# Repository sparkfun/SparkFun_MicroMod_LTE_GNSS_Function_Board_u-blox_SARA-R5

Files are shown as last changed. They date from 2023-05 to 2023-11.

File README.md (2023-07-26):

SparkFun MicroMod LTE GNSS Function Board - u-blox SARA-R5
========================================

SparkFun MicroMod LTE GNSS Function Board - u-blox SARA-R5 (https://www.sparkfun.com/products/18431)

[*SparkFun MicroMod LTE GNSS Function Board - u-blox SARA-R5 (DEV-18431)*](https://www.sparkfun.com/products/18431)

Using the u-blox SARA-R510M8S, this function board adds LTE and GNSS capabilities to the MicroMod EcoSystem.

Documentation
--------------
* **[Library](https://github.com/sparkfun/SparkFun_u-blox_SARA-R5_Arduino_Library)** - Arduino library for the SparkFun MicroMod LTE GNSS Function Board u-blox SARA-R5.
* **[Hookup Guide](https://docs.sparkfun.com/SparkFun_MicroMod_LTE_GNSS_Function_Board_u-blox_SARA-R5)** - Basic hookup guide for the SparkFun MicroMod LTE GNSS Function Board u-blox SARA-R5.

Product Versions
----------------
* [DEV-18431](https://www.sparkfun.com/products/18431) - Initial release, v1.1

License Information
-------------------

This product is _**open source**_!

Please review the LICENSE.md file for license information.

If you have any questions or concerns on licensing, please contact technical support on our [SparkFun forums](https://forum.sparkfun.com/viewforum.php?f=152).

Distributed as-is; no warranty is given.

- Your friends at SparkFun.

_<COLLABORATION CREDIT>_

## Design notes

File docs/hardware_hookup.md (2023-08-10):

If you have not already, make sure to check out the Getting Started with MicroMod: Hardware Hookup for information on inserting your Processor and Function Boards to the Main Board.

<div style="text-align: center">
  <table>
    <tr>
      <td>
        <a href="https://learn.sparkfun.com/tutorials/getting-started-with-micromod#hardware-hookup">
          <div style="text-align: center">Getting Started with MicroMod: Hardware Hookup</div>
          <hr />
          <h3 style="text-align: left">
            <b>Getting Started with MicroMod: Hardware Hookup</b>
          </h3>
        </a>
      </td>
    </tr>
  </table>
  </div>

### Inserting a SIM Card

!!!note
    ####Activate Your Hologram SIM
    If you're using a SIM card from Hologram, you'll need to follow a few quick steps to activate your SIM card.
    <ol>
      <li><a href="https://dashboard.hologram.io/">Log in</a> to your Hologram account, or <a href="https://dashboard.hologram.io/account/register">create one</a>.</li>
      <li>Click the blue <strong>+ Activate SIM</strong> button in the upper-right-corner of your Dashboard.</li>
      <br>
      <p style="text-align:center;"> <a href="https://cdn.sparkfun.com/assets/learn_tutorials/8/1/6/hologram-activate-sim.png">Activate hologram SIM</a></p>
      <br>
      <li>Select your plan – in most cases “Maker Flexible” is the way to go, but you can upgrade.</li>
      <li>Enter your SIM card’s CCID. This number can be found printed on both your nano-SIM card and in the larger digits below the bar code. Then select continue.</li>
      <li>Next you can decide whether to enable auto-refill or not and continue. Finally, you’ll be greeted with a summary page – hit “Activate” and you’re ready to go!</li>
    </ol>
    <p>For more help activating your Hologram SIM card, check out their <a  href="https://hologram.io/docs/guide/connect/connect-device/">Connect Your Device</a> documentation.</p>

Insert the SIM card into the nano SIM socket until it clicks. In this case, we used a [Hologram card](https://www.sparkfun.com/products/17117).

<div style="text-align: center;">
  <table>
    <tr align="center">
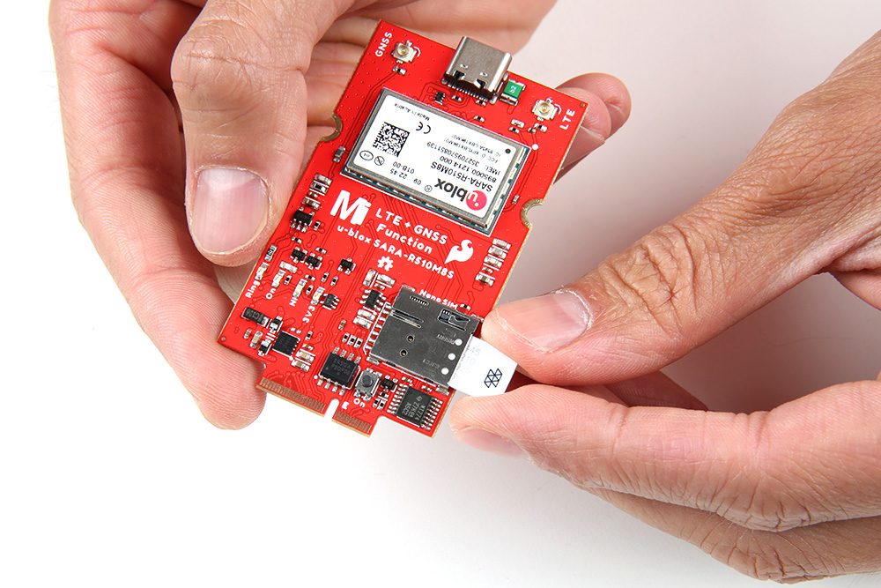
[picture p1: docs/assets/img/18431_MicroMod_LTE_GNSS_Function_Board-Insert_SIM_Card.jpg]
Insert Nano SIM Card
     <td></td>
    </tr>
  </table>
</div>

### Processor Board

Align the Processor Board's key into its M.2 connector's socket. Insert the board at an angle (~25°), push down, and tighten the screw. In this case, we had the MicroMod ESP32 Processor Board secured in the M.2 connector socket. Depending on your application, you may have a different Processor Board.

<div style="text-align: center;">
  <table>
    <tr align="center">
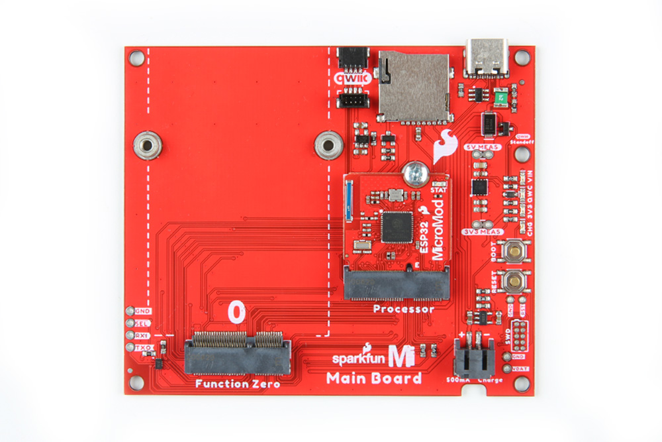
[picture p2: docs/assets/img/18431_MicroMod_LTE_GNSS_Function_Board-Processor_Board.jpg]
Insert Processor Board into Main Board
     <td></td>
    </tr>
  </table>
</div>

!!!note
    There are a variety of MicroMod Processor Boards available. However, we recommend using the ESP32, Artemis, and SAMD51 Processor Boards as these were tested to work with the SARA-R5. For the scope of this tutorial, we will be using the ESP32 Processor Board. The caveat when using the ESP32 Processor Board is that you will need to configure the pin that is connected to the voltage regulator's enable pin. This pin is used to upload code and when the ESP32 boots up. After uploading code and/or when the ESP32 has finished booting up, you will need to configure the pin as an input pullup in the `setup()`.

### Function Board

Align the Function Board's key into its M.2 connector's socket. Insert the board at an angle (~25°), push down, and tighten one of the screw to hold the board down. Attach the second screw on the other side of the board. Once the board is aligned, tighten both screws fully to secure the board.

<div style="text-align: center;">
  <table>
    <tr align="center">
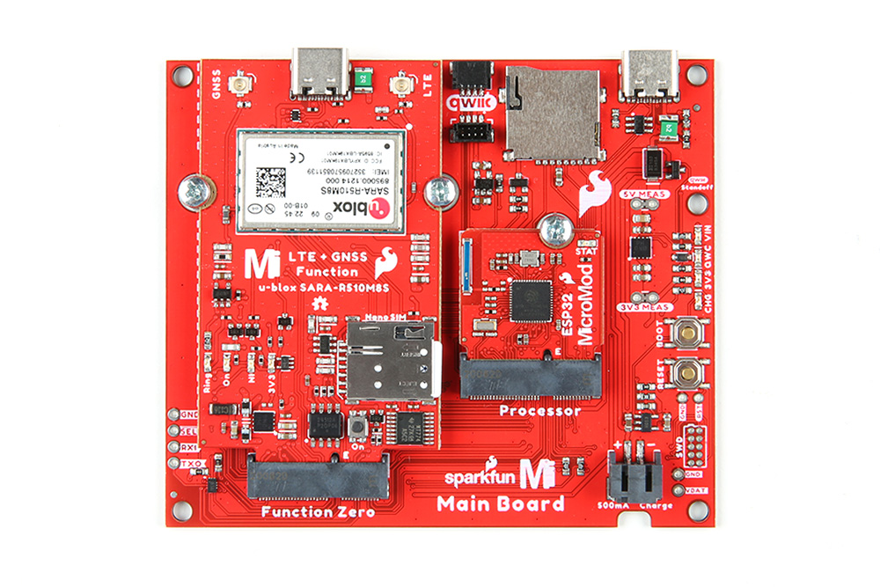
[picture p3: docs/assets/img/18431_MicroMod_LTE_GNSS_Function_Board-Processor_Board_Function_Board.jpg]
Insert Function Board into Main Board
     <td></td>
    </tr>
  </table>
</div>

### Attaching Antennas

Once the Function Boards are secure, attach any remaining cables, antennas, or components that your application may need. In this case, we would need to attach the LTE antenna, GNSS antenna, and a u.FL to SMA adapter for each antenna. For each antenna, connect the SMA connectors together and secure the connection using the hex nut until it is finger-tight. Then plug in the u.FL side of the cable into the board's u.FL connector. If you need tips on plugging in the U.FL connector, then check out our [U.FL tutorial](https://learn.sparkfun.com/tutorials/three-quick-tips-about-using-ufl).

<div style="text-align: center;">
  <table>
    <tr align="center">
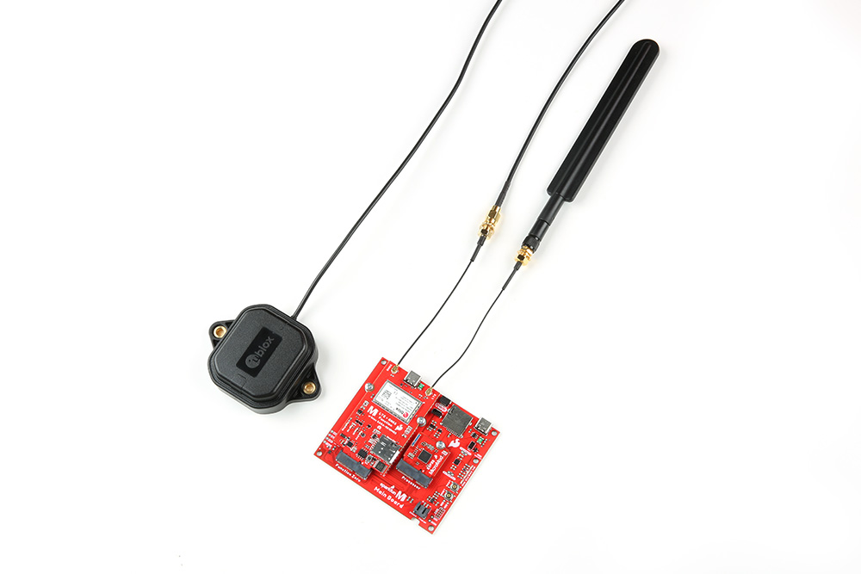
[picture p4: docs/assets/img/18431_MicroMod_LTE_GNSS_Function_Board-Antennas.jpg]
Connect u.FL to SMA cables to LTE and GNSS multi-band antenna
     <td></td>
    </tr>
  </table>
</div>

### USB Cable

Last but not least, insert a cable to the Main Board's USB port. This is useful for programming the ESP32 Processor Board, power, and serial communication.

<div style="text-align: center;">
  <table>
    <tr align="center">
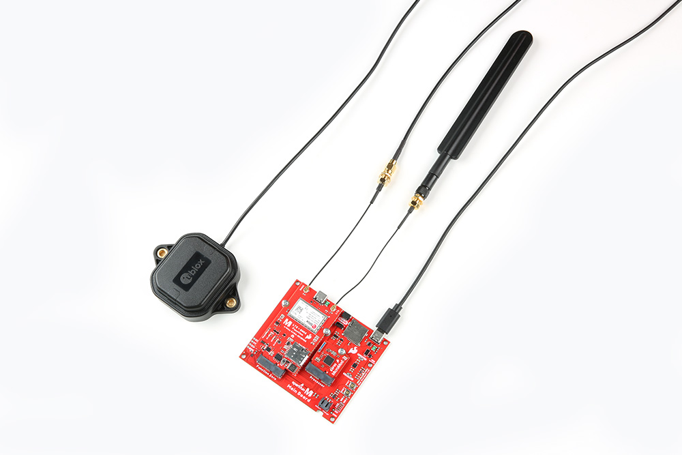
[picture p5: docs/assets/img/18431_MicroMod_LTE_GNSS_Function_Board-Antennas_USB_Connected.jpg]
USB Cable into Main Board
     <td></td>
    </tr>
  </table>
</div>

!!!note
    The USB port on the SARA-R5 Function Board is for diagnostics and is currently unavailable. While you can connect to the port for power, there currently is not much support for the diagnostics.

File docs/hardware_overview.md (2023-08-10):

We've broken out the SARA-R5 module (specifically the **SARA-R510M8S-01B**) to a MicroMod Function Board. Due to the design of the Function Board, we've rotated the board 180° relative to the label in the image shown below. In this section, we will highlight relevant components on the board. For more information about the u-blox SARA-R510M8S module, make sure to check the Resources tab.

<div style="text-align: center;">
  <table>
    <tr align="center">
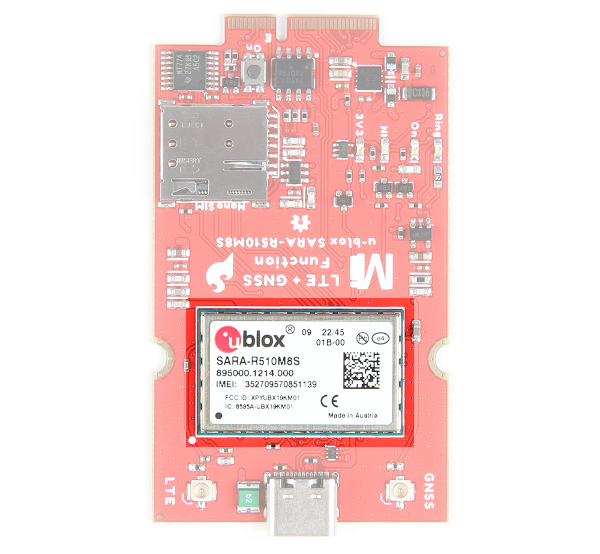
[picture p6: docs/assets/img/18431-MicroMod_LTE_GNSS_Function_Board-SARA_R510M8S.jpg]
SARA-R5 highlighted
     <td></td>
    </tr>
  </table>
</div>

### Power

The Function Board receives power typically from MicroMod Main Board's M.2 socket. Depending on your application, power can be provided via the Main Board's USB or a single cell LiPo Battery. If the Function Board's USB is also connected, a Schottky protection diode (the little rectangular black IC by the USB C connector) is included to prevent conflicting voltages. A resettable fuse is also included next to the USB connector as well. Power for the system is regulated down for the function board from the 3.3V AP7361C voltage regulator (square IC by the bottom left of the board). A dedicated 3.3V AP2112K voltage regulator (5-pin black IC) is also provided when using an active GNSS antenna. Additionally, the board includes an IC for voltage level translation (16 pin black IC on the bottom right of the board) for certain pins on the SARA-R510M8S.

<div style="text-align: center;">
  <table>
    <tr align="center">
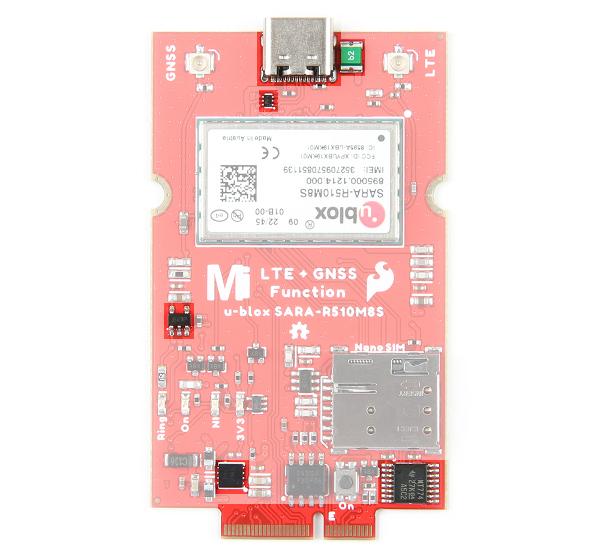
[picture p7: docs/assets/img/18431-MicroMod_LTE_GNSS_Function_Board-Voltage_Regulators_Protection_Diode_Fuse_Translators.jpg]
USB, M.2 Edge, voltage regulators, protection diodes, fuse, and logic translators highlighted
     <td></td>
    </tr>
  </table>
</div>

### USB Type C Connector

Users can connect the module to a USB port. This can power the module as well. A Schottky protection diode is included to prevent conflicting voltages when the Main Board is connected to a power source. A resettable fuse is also provided. Compared to other u-blox modules, you will this is for the diagnostic interface and not to for flashing new firmware.

<div style="text-align: center;">
  <table>
    <tr align="center">
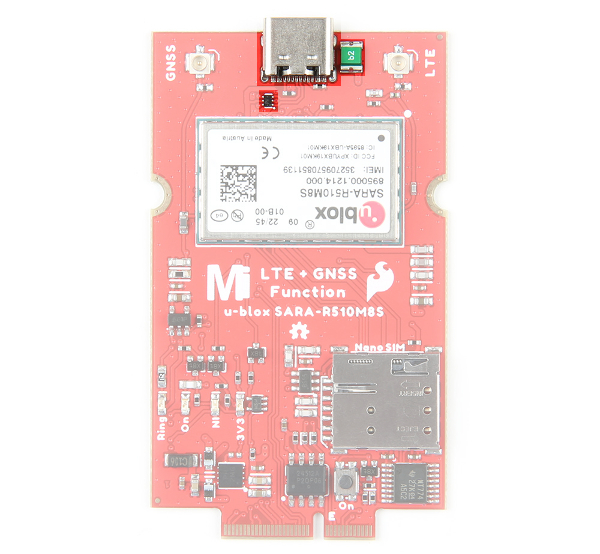
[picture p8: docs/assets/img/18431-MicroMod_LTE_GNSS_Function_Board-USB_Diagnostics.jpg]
USB, protection diodes, and resettable fuse highlighted
     <td></td>
    </tr>
  </table>
</div>

!!!note
    Please consult the [SARA R5 Integration Manual](https://cdn.sparkfun.com/assets/f/8/5/a/6/SARA-R5_SysIntegrManual__UBX-19041356_.pdf) for more details on using the diagnostic interface. You cannot (currently) upgrade the SARA via the diagnostic interface. Using the diagnostic interface is beyond the scope of this tutorial.

### u.FL Connectors for LTE and GNSS

The MicroMod Main Board was intended to be included in an enclosure. Thus, the function board includes two u.FL connectors for the LTE and GNSS antennas. You will need a [u.FL to SMA adapter](https://www.sparkfun.com/products/9145) for each antenna.

<div style="text-align: center;">
  <table>
    <tr align="center">
     <td><a href="../assets/img/18431-MicroMod_LTE_GNSS_Function_Board-USB_Diagnostics.jpg">USB, protection diodes, and resettable fuse highlighted</a></td>
    </tr>
  </table>
</div>

### Nano SIM Socket

To connect to an LTE network, you will need a nano SIM card.

<div style="text-align: center;">
  <table>
    <tr align="center">
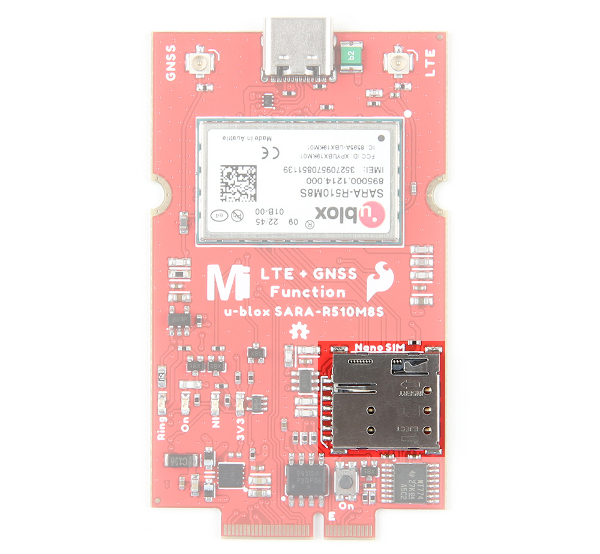
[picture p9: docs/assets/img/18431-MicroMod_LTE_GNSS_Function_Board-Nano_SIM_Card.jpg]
Nano SIM Socket highlighted
     <td></td>
    </tr>
  </table>
</div>

### On Button

The "ON" button to configure the SARA-R5 power settings. There are three modes: power on, power saving mode (PSM), or power OFF. Press and hold the button down to enter each mode for about 3 seconds. When fully powered, the LED will be bright red. In power saving mode, the LED will dim. When powered off, the LED will turn off.

<div style="text-align: center;">
  <table>
    <tr align="center">
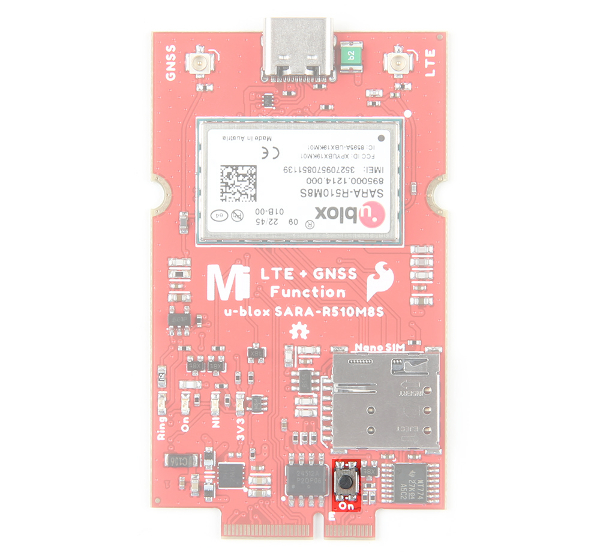
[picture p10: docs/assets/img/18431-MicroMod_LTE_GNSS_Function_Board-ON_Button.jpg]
On Button highlighted
     <td></td>
    </tr>
  </table>
</div>

### LEDs

The board includes four status LEDs:

* **3.3V** &mdash; When lit, this indicates 3.3V power is available.
* **Ring** &mdash; When lit, this indicates when there is an event.
* **NI** &mdash; The LTE Network Indicator LED shows the cellular network status when the SARA-R5's GPIO1 is configured to act as a network status indicator output. The NI LED alternates from full Off (No service), full On (Data Transmission) as well as various pulse lengths to show different network statuses. Refer to section 17.1.3 of the AT Command Manual for the AT commands and description of this LED and the GPIO1/NI pin's behavior for different network states.
* **LTE ON** &mdash; The LTE ON LED indicates when the SARA-R5 module is powered on. When the LED is dim, this indicates that the SARA-R5 is in power saving mode. When the LED is off, the modules is powered off.

<div style="text-align: center;">
  <table>
    <tr align="center">
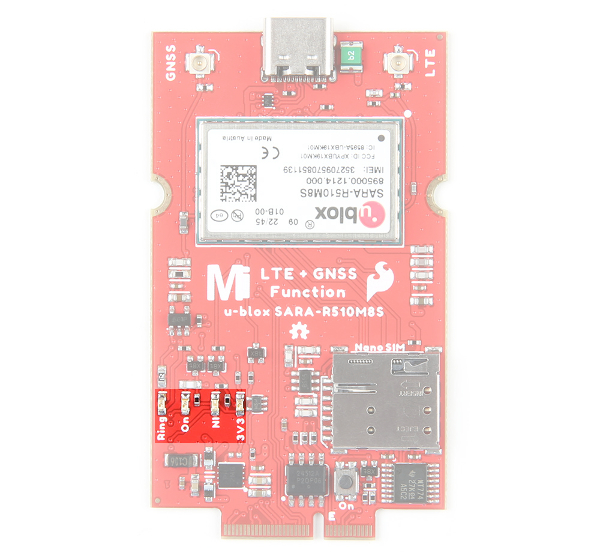
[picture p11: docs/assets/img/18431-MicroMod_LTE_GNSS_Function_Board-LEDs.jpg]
LEDs highlighted
     <td></td>
    </tr>
  </table>
</div>

### Jumpers

!!!note
    Never worked with solder jumpers and PCB traces before or need a quick refresher? Check out our [How to Work with Solder Jumpers and PCB Traces](https://learn.sparkfun.com/tutorials/how-to-work-with-jumper-pads-and-pcb-traces) tutorial for detailed instructions and tips.

The back of the board includes various jumpers:

* **USB_SHLD** &mdash; By default, this jumper is closed and connects the USB Type C connector's shield pin to GND. Cut this to isolate the USB Type C connector's shield pin.
* **3V3_LED** &mdash; By default, this jumper is closed and connects to the output of the 3.3V voltage regulator. This is to indicate when 3.3V power is available for the SARA-R5 module. Cut this jumper to disable the 3.3V power LED and reduce the total current draw of the function board.
* **ANT_REG_EN** &mdash; By default, this jumper is closed and connects to the 3.3V AP2112K voltage regulator enable pin to the function board's general purpose I/O pin `F7`. The voltage regulator is controlled through software to provide power to an active GNSS antenna.
* **LTE_PWR_ON** &mdash; By default, this jumper is closed and connects the LTE power on pin to the function board's general purpose I/O pin `F5`. The LTE_PWR_ON pin is active low. This pin can be controlled through software or manually with the button.
* **LTE_ON_LED** &mdash; By default, this jumper is closed and connects to the LTE ON LED. Cut this to disable LED and reduce the total current draw of the function board.
* **LTE_ON** &mdash; By default, this jumper is closed and connects to the LTE ON pin to the function board's general purpose I/O pin `F1`. Cut this to disable LED and reduce the total current draw of the function board.
* **LTE_RST** &mdash; By default, this jumper is closed and connects the LTE reset pin to the function board's general purpose I/O pin `F2`. The LTE_RST pin is active low. This pin is controlled through software and will reset the SARA-R5 module.
* **NI_LED** &mdash;  By default, this jumper is closed and connects to the LTE network indicator pin to an LED. Cut this to disable LED and reduce the total current draw of the function board.
* **LTE_NI** &mdash; By default, this jumper is closed and connects the LTE network indicator pin to the function board's general purpose I/O pin `F0`. The LTE_NI pin is active low.
* **LTE_RI_LED** &mdash; By default, this jumper is closed and connects the UART Ring Indicator to an LED. Cut this jumper to disable the 3.3V power LED and reduce the total current draw of the function board.
* **I2C** &mdash;  By default, this three way jumper connects the 2.2k&ohm; pull-up resistors to the I<sup>2</sup>C data lines. Most of the time you can leave these alone unless your project requires you to [disconnect the pull-up resistors](https://learn.sparkfun.com/tutorials/i2c/all#i2c-at-the-hardware-level).
* **WP** &mdash;  By default, this jumper is open. Adding solder to the jumper pad will disable write protect for the EEPROM.

<div style="text-align: center;">
  <table>
    <tr align="center">
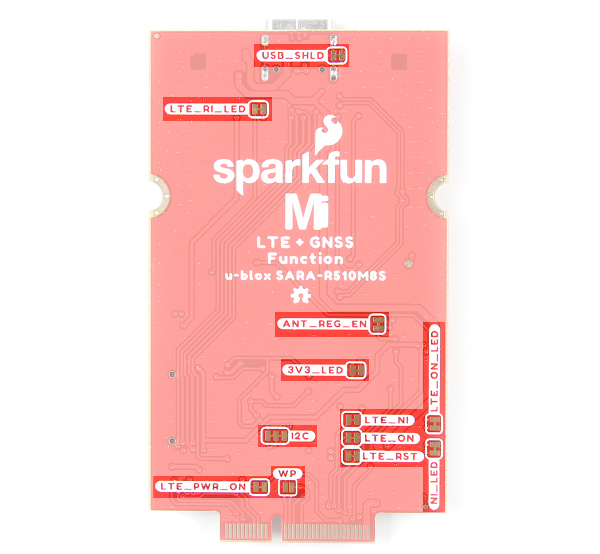
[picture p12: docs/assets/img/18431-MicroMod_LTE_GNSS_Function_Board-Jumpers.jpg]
Jumpers highlighted
     <td></td>
    </tr>
  </table>
</div>

### EEPROM

The board includes an I<sup>2</sup>C EEPROM. Unfortunately, this is not available for the user and was meant to hold board specific information.

<div style="text-align: center;">
  <table>
    <tr align="center">
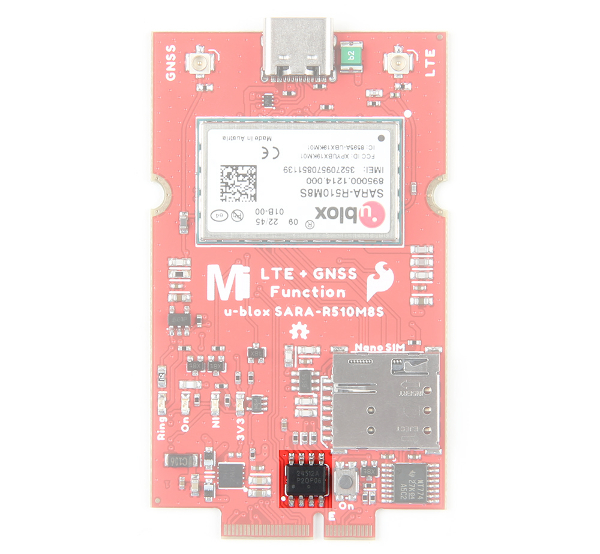
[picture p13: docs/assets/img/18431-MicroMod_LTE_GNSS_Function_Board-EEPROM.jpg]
EEPROM highlighted
     <td></td>
    </tr>
  </table>
</div>

### Hardware Pinout

The LTE GNSS Function Board breaks out the SARA-R510M8S pins out to the edge of the board when connecting to a M.2 connector.

<div style="text-align: center;">
  <table>
    <tr align="center">
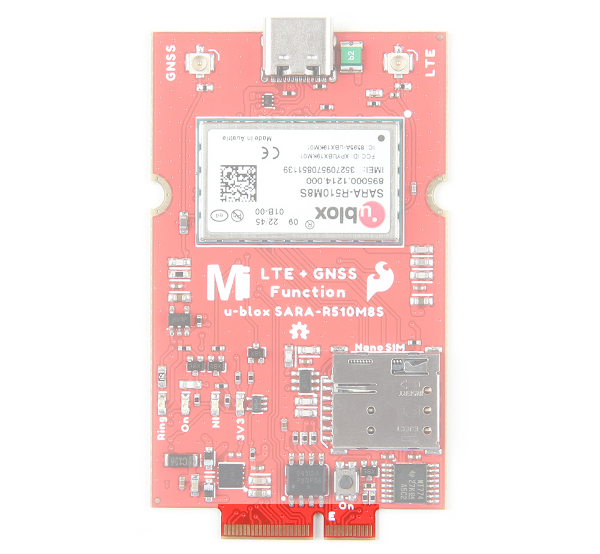
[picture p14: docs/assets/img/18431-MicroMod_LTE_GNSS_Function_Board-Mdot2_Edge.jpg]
Function Board Edge Pins
     <td></td>
    </tr>
  </table>
</div>

### Board Dimensions

The board uses the standard MicroMod Function Board size which measures about 37.49mm x 61.00mm (1.48" x 2.40").

<div style="text-align: center;">
  <table>
    <tr align="center">
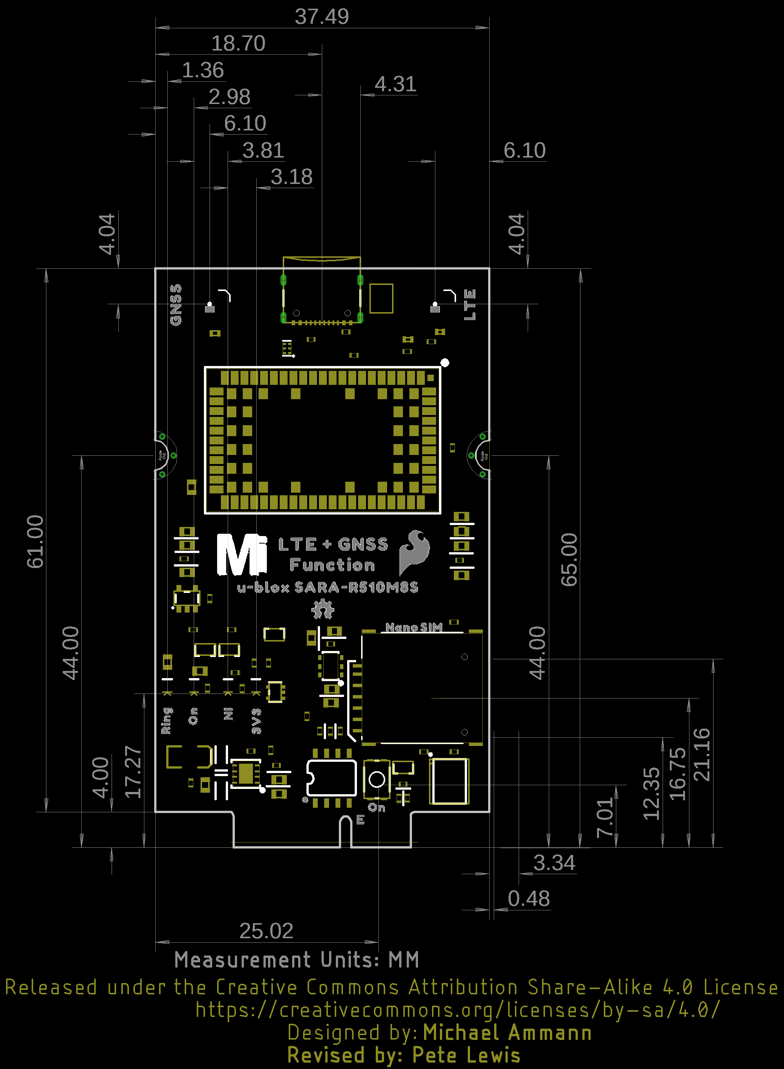
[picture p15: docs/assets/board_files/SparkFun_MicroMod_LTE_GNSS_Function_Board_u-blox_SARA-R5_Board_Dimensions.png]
Board Dimensions
     <td></td>
    </tr>
  </table>
</div>

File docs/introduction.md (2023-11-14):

The [SparkFun SARA-R5 LTE GNSS Function Board](https://www.sparkfun.com/products/18431) is a robust development tool for u-blox&apos;s impressive SARA-R510M8S module. The SARA-R510M8S combines u-blox&apos;s UBX-R5 cellular chipset with their M8 GNSS receiver chipset to provide a 5G-Ready wireless IoT device complete with positioning data all on a single chip. As an asset tracker, the LTE GNSS Function Board offers Secure Cloud LTE-M communication for multi-regional use and has an integrated u-blox M8 GNSS receiver for accurate positioning information.

<center>
<div class="grid cards" style="width:500px;" markdown>

-   <a href="https://www.sparkfun.com/products/18431">
      <figure markdown>
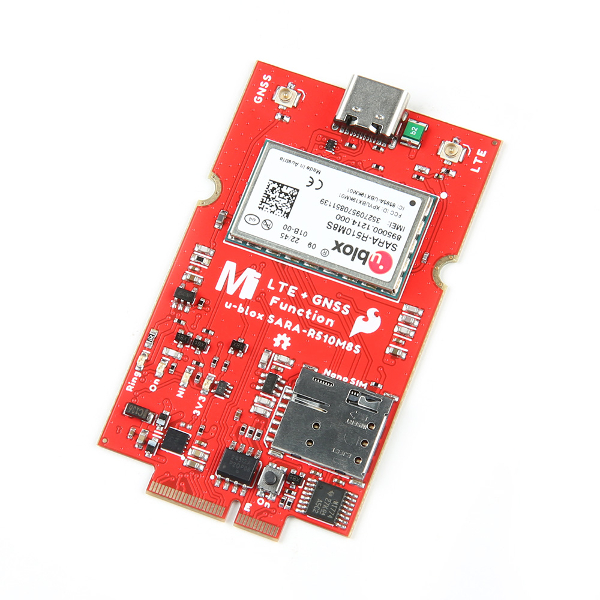
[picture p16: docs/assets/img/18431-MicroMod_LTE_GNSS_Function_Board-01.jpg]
SparkFun LTE GNSS Function Board - SARA-R5
        
      </figure>
    </a>

    ---

    <a href="https://www.sparkfun.com/products/18431">
      <b>SparkFun LTE GNSS Function Board - SARA-R5</b>
      <br />
      DEV-18431
      <br />
      <center>[Purchase from SparkFun :fontawesome-solid-cart-plus:](https://www.sparkfun.com/products/18431){ .md-button .md-button--primary }</center>
    </a>

</div>
</center>

<div style="text-align: center;">
  <iframe width="560" height="315" src="https://www.youtube.com/embed/R37YaJobexs" title="YouTube video player" frameborder="0" allow="accelerometer; autoplay; clipboard-write; encrypted-media; gyroscope; picture-in-picture; web-share" allowfullscreen></iframe>
</div>

The UBX-R5 chipset supports many different forms of data communication from full TCP/IP sockets and packet switched data, through HTTP Get/Put/Post, FTP (the SARA has a built-in file system), or ping to good old SMS text messaging! The built-in u‑blox M8 GNSS receiver provides accurate and reliable positioning with a separate GNSS antenna interface for an external antenna. Both the GNSS antenna and LTE connections are made via a pair of u.FL connectors. A nano SIM card slot is also included as well.

Utilizing our handy M.2 MicroMod connector, no soldering is required to connect it to your system. Simply match up the key on your processor and function board's beveled edge connector to their respective key on the M.2 connector, then secure them to the Main Board with screws.

This Function Board provides access to the UART (default configuration) with a Processor Board. The USB pins are also broken out to a USB-C connector for diagnostic purposes. Status LEDs are included for 3.3V, Ring Indicator, LTE ON, and LTE Network Indicator. A button is included for LTE Power On.

### Required Materials

To follow along with this tutorial, you will need the following materials. You may not need everything though depending on what you have. Add it to your cart, read through the guide, and adjust the cart as necessary.

* 1x [SparkFun MicroMod - Single Board [DEV-20748]](https://www.sparkfun.com/products/20594)
* 1x [SparkFun MicroMod ESP32 Processor [WRL-16781]](https://www.sparkfun.com/products/16781)
    * There are a variety of MicroMod Processor Boards available. However, we recommend using the ESP32, Artemis, and SAMD51 Processor Boards as these were tested to work with the SARA-R5. For the scope of this tutorial, we will be using the ESP32 Processor Board. The caveat when using the ESP32 Processor Board is that you will need to configure the pin that is connected to the voltage regulator's enable pin. This pin is used to upload code and when the ESP32 boots up. After uploading code and/or when the ESP32 has finished booting up, you will need to configure the pin as an input pullup in the `setup()`.
* 1x [SparkFun LTE GNSS Function Board - SARA-R5 [DEV-18431]](https://www.sparkfun.com/products/18431)
* 1x USB-C cable
    * Our [USB 2.0 A to C Cable [CAB-15092]](https://www.sparkfun.com/products/15092) will do nicely
    * Our [USB 3.1 A to C Cable [CAB-14743]](https://www.sparkfun.com/products/14743) is a good choice too
* 1x SIM Card<sup>*</sup>
    * [Hologram SIM Card [CEL-17117]](https://www.sparkfun.com/products/17117)
* 1x [GNSS Multi-Band Magnetic Mount Antenna - 5m (SMA) [GPS-15192]](https://www.sparkfun.com/products/15192)
* 1x [LTE Hinged External Antenna - 698MHz-2.7GHz, SMA Male [CEL-16432]](https://www.sparkfun.com/products/16432)
* 2x [Interface Cable SMA to U.FL
 [WRL-09145]](https://www.sparkfun.com/products/9145)
* 1x [SparkFun Mini Screwdriver [TOL-09146]](https://www.sparkfun.com/products/9146)

!!! note "<sup>*</sup> Note"
    <sup>If you use your own SIM card, please check that your chosen service provider offers LTE-M coverage for your area before purchasing.</sup>

<div class="grid cards col-4" markdown>

-   <a href="https://www.sparkfun.com/products/20748">
      <figure markdown>
        SparkFun MicroMod - Single Board
      </figure>
    </a>

    ---

    <a href="https://www.sparkfun.com/products/20748">
      <b>SparkFun MicroMod - Single Board</b>
      <br />
      DEV-20748
    </a>
<!-- ----------WHITE SPACE BETWEEN PRODUCTS---------- -->
-   <a href="https://www.sparkfun.com/products/16781">
      <figure markdown>
        SparkFun MicroMod ESP32 Processor
      </figure>
    </a>

    ---

    <a href="https://www.sparkfun.com/products/14743">
      <b>SparkFun MicroMod ESP32 Processor</b>
      <br />
      WRL-16781
    </a>
<!-- ----------WHITE SPACE BETWEEN PRODUCTS---------- -->
-   <a href="https://www.sparkfun.com/products/18431">
      <figure markdown>
        SparkFun LTE GNSS Function Board - SARA-R5
      </figure>
    </a>

    ---

    <a href="https://www.sparkfun.com/products/18431">
      <b>SparkFun LTE GNSS Function Board - SARA-R5</b>
      <br>
      DEV-18431
    </a>
<!-- ----------WHITE SPACE BETWEEN PRODUCTS---------- -->
-   <a href="https://www.sparkfun.com/products/15092">
      <figure markdown>
       USB 2.0 A to C Cable
      </figure>
    </a>

    ---

    <a href="https://www.sparkfun.com/products/15092">
      <b>USB 2.0 A to C Cable</b>
      <br>
      CAB-15092
    </a>
<!-- ----------WHITE SPACE BETWEEN PRODUCTS---------- -->
-   <a href="https://www.sparkfun.com/products/17117">
      <figure markdown>
        Hologram SIM Card
      </figure>
    </a>

    ---

    <a href="https://www.sparkfun.com/products/17117">
      <b>Hologram SIM Card</b>
      <br>
      CEL-17117
    </a>
<!-- ----------WHITE SPACE BETWEEN PRODUCTS---------- -->
-   <a href="https://www.sparkfun.com/products/15192">
      <figure markdown>
        GNSS Multi-Band Magnetic Mount Antenna - 5m (SMA)
      </figure>
    </a>

    ---

    <a href="https://www.sparkfun.com/products/15192">
     <b>GNSS Multi-Band Magnetic Mount Antenna - 5m (SMA)</b>
     <br>
     GPS-15192
    </a>
<!-- ----------WHITE SPACE BETWEEN PRODUCTS---------- -->
-   <a href="https://www.sparkfun.com/products/16432">
      <figure markdown>
        LTE Hinged External Antenna - 698MHz-2.7GHz, SMA Male
      </figure>
    </a>

    ---

    <a href="https://www.sparkfun.com/products/16432">
      <b>LTE Hinged External Antenna - 698MHz-2.7GHz, SMA Male</b>
      <br>
      CEL-16432
    </a>
<!-- ----------WHITE SPACE BETWEEN PRODUCTS---------- -->
-   <a href="https://www.sparkfun.com/products/9145">
      <figure markdown>
        Interface Cable SMA to U.FL
      </figure>
    </a>

    ---

    <a href="https://www.sparkfun.com/products/9145">
      <b>Interface Cable SMA to U.FL</b>
      <br>
      WRL-09145
    </a>
<!-- ----------WHITE SPACE BETWEEN PRODUCTS---------- -->
-   <a href="https://www.sparkfun.com/products/9146">
      <figure markdown>
        SparkFun Mini Screwdriver
      </figure>
    </a>

    ---

    <a href="https://www.sparkfun.com/products/9146">
      <b>SparkFun Mini Screwdriver</b>
      <br>
      TOL-09146
    </a>
<!-- ----------WHITE SPACE BETWEEN PRODUCTS---------- -->  

</div>

!!! note
    The SMA connections on the antennas are standard polarity. Antennas with reverse-polarity connectors are not suitable when connecting to the LTE GNSS Function Board and u.FL to SMA cables.

### Suggested Reading

If you aren't familiar with the MicroMod Ecosystem, we recommend reading [here for an overview](https://www.sparkfun.com/micromod).

<div style="text-align: center">
  <table style="border-style:none">
    <tr>
     <td>
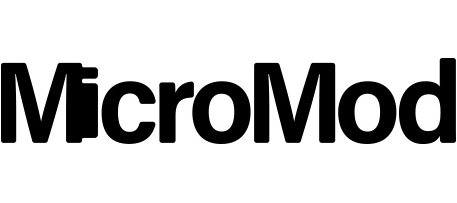
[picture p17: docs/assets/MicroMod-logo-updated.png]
MicroMod Ecosystem Click to learn more about the MicroMod Ecosystem!
     <div style="text-align: center">
     </div>
    </td>
    </tr>
    <tr>
      <td><div style="text-align: center"><i><a href="https://www.sparkfun.com/micromod">MicroMod Ecosystem</a></i></div></td>
    </tr>
  </table>
</div>

If you aren’t familiar with the following concepts, we also recommend checking out a few of these tutorials before continuing.

<div class="grid cards col-4" markdown>

-   <a href="https://learn.sparkfun.com/tutorials/getting-started-with-micromod">
      <figure markdown>
        Getting Started with MicroMod
      </figure>
    </a>

    ---

    <a href="https://learn.sparkfun.com/tutorials/getting-started-with-micromod">
      <b>Getting Started with MicroMod</b>
    </a>

-   <a href="https://learn.sparkfun.com/tutorials/micromod-esp32-processor-board-hookup-guide">
      <figure markdown>
        ESP32 Processor Board Tutorial
      </figure>
    </a>

    ---

    <a href="https://learn.sparkfun.com/tutorials/micromod-esp32-processor-board-hookup-guide">
      <b>MicroMod ESP32 Processor Board Hookup Guide</b>
    </a>

-   <a href="https://learn.sparkfun.com/tutorials/micromod-main-board-hookup-guide-v2">
      <figure markdown>
        MicroMod Main Board Hookup Guide V2
      </figure>
    </a>

    ---

    <a href="https://learn.sparkfun.com/tutorials/micromod-main-board-hookup-guide-v2">
      <b>MicroMod Main Board Hookup Guide V2</b>
    </a>

-   <a href="https://learn.sparkfun.com/tutorials/installing-an-arduino-library">
      <figure markdown>
        Installing an Arduino Library
      </figure>
    </a>

    ---

    <a href="https://learn.sparkfun.com/tutorials/installing-an-arduino-library">
      <b>Installing an Arduino Library</b>
    </a>

-   <a href="https://learn.sparkfun.com/tutorials/terminal-basics">
      <figure markdown>
        Serial Terminal Basics
      </figure>
    </a>

    ---

    <a href="https://learn.sparkfun.com/tutorials/terminal-basics">
      <b>Serial Terminal Basics</b>
    </a>

-   <a href="https://learn.sparkfun.com/tutorials/how-to-work-with-jumper-pads-and-pcb-traces">
      <figure markdown>
        How to Work with Jumper Pads and PCB Traces
      </figure>
    </a>

    ---

    <a href="https://learn.sparkfun.com/tutorials/how-to-work-with-jumper-pads-and-pcb-traces">
      <b>How to Work with Jumper Pads and PCB Traces</b>
    </a>
</div>

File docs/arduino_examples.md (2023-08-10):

<!--

<div style="text-align: center;">
  <table>
    <tr align="center">
     <td><a href="../assets/img/"><img src="../assets/img/" width="600" height="600" alt=""></a></td>
    </tr>
  </table>
</div>

-->

The SparkFun u-blox SARA-R5 Arduino Library includes several examples to cover how to configure and use different features of the SARA-R5 module.

Make sure to go through the following examples to get the SARA-R5 registered and configured properly on your mobile network:

- Example 3 - Network Info
- Example 4 - Register Operator
- Example 7 - Configure Packet Switched Data

### Example 1 - GNSS GPRMC

The first example enables the GNSS receiver and reads the GPRMC message for position, speed and time data. Open the example by navigating to **File** > **Examples** > **SparkFun u-blox SARA-R5 Arduino Library** > **SARA-R5_Example1_GNSS_GPRMC**.

Select your board in the Tools menu (in our case **SparkFun ESP32 MicroMod**) and the correct Port it enumerated on and click "Upload". After uploading the code, open the [Serial Monitor](https://learn.sparkfun.com/tutorials/terminal-basics) or terminal emulator of your choice with the baud rate set to **115200**. The code waits for a keyboard input from the user before progressing and running the setup and loop. After user input, the code prints out GPS data every second when there is a GPS lock.

<div style="text-align: center;">
  <table>
    <tr align="center">
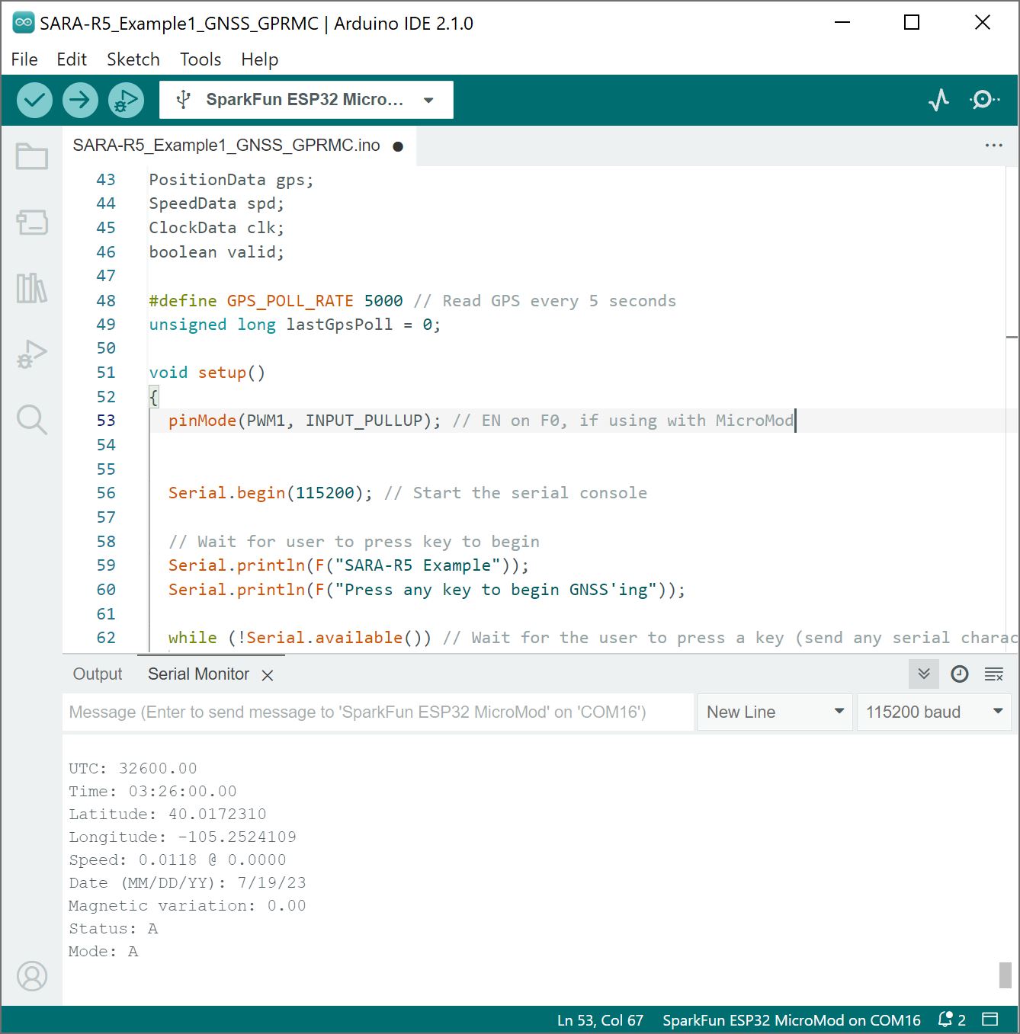
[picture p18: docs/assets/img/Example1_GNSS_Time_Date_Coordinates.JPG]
     <td></td>
    </tr>
  </table>
</div>

!!!note
    Heads up! Make sure your GNSS antenna has a clear view of the open sky. Placing the antenna outdoors away from large objects (buildings, large trees, etc.) is best but if necessary you can usually place the antenna in a window that has a view of the sky to get a lock.

####Code to Note

This function organizes the GPS data to print out neatly whenever the data returns as valid:

    void printGPS(void)
    {
      Serial.println();
      Serial.println("UTC: " + String(gps.utc));
      Serial.print("Time: ");
      if (clk.time.hour < 10) Serial.print('0'); // Print leading 0
      Serial.print(String(clk.time.hour) + ":");
      if (clk.time.minute < 10) Serial.print('0'); // Print leading 0
      Serial.print(String(clk.time.minute) + ":");
      if (clk.time.second < 10) Serial.print('0'); // Print leading 0
      Serial.print(String(clk.time.second) + ".");
      if (clk.time.ms < 10) Serial.print('0'); // Print leading 0
      Serial.println(String(clk.time.ms));
      Serial.println("Latitude: " + String(gps.lat, 7));
      Serial.println("Longitude: " + String(gps.lon, 7));
      Serial.println("Speed: " + String(spd.speed, 4) + " @ " + String(spd.cog, 4));
      Serial.println("Date (MM/DD/YY): " + String(clk.date.month) + "/" +
        String(clk.date.day) + "/" + String(clk.date.year));
      Serial.println("Magnetic variation: " + String(spd.magVar));
      Serial.println("Status: " + String(gps.status));
      Serial.println("Mode: " + String(gps.mode));
      Serial.println();
    }

### Example 2 - Identification

The second example prompts the LTE module to read the SARA-R5's identification information:

- Manufacturer ID
- Model
- Firmware Version
- Serial Number
- IMEI ID
- IMSI ID
- SIM CCID
- Subscriber Number (from the SIM)
- Capabilities
- SIM state

This example primarily functions as a check to make sure the SARA-R5 is working properly and the SIM card is detected then polls the SIM status in the main loop. Upload the code and open a terminal window with the baud set to **115200**. The code initializes the SARA-R5 and after a user input, initializes the SARA-R5 and prints out the ID information and SIM state.

Open the example by navigating to **File** > **Examples** > **SparkFun u-blox SARA-R5 Arduino Library** > **SARA-R5_Example2_Identification**.

If you have not already, select your board in the Tools menu (in our case **SparkFun ESP32 MicroMod**) and the correct Port it enumerated on and click "Upload". After uploading the code, open the Serial Monitor with the baud rate set to **115200**. Again, the code waits for a keyboard input from the user before progressing and running the setup and loop.

Make sure to wait for the blue NI LED to light up first before sending a character through the terminal window. Once there is a network in range, send a character to run the example. You will see the SARA-R5's identification information printed out.

<div style="text-align: center;">
  <table>
    <tr align="center">
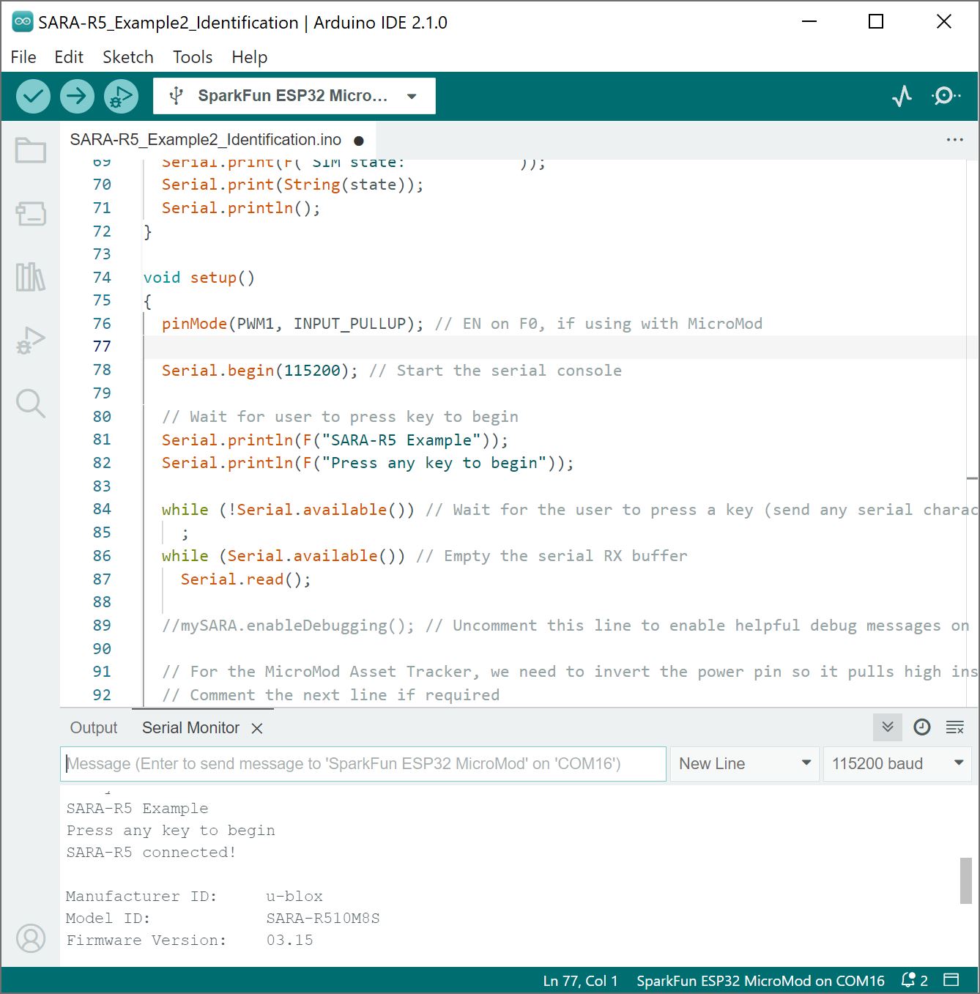
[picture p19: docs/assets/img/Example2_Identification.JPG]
     <td></td>
    </tr>
  </table>
</div>

### Example 3 - Network Info

This example verifies the SARA-R5 is receiving an LTE signal on a selected network and prints out the network information and IDs. The code creates the SARA-R5 object and assigns a network operator value. Depending on the network for your SIM card uses, adjust this line:

    const mobile_network_operator_t MOBILE_NETWORK_OPERATOR = MNO_GLOBAL;

Open the example by navigating to **File** > **Examples** > **SparkFun u-blox SARA-R5 Arduino Library** > **SARA-R5_Example3_NetworkInfo**.

If you have not already, select your board in the Tools menu (in our case **SparkFun ESP32 MicroMod**) and the correct Port it enumerated on and click "Upload". After uploading the code, open the Serial Monitor with the baud rate set to **115200**. Wait for the blue NI LED to light up and then send a keyboard input.

After initializing everything needed, the code attempts to set the Network Profile to the Mobile Network Operator entered. If successful, the code prints out the RSSI (Received Signal Strength), Network Registration Status and Context IDs, Access Point Names and IP Addresses.

<div style="text-align: center;">
  <table>
    <tr align="center">
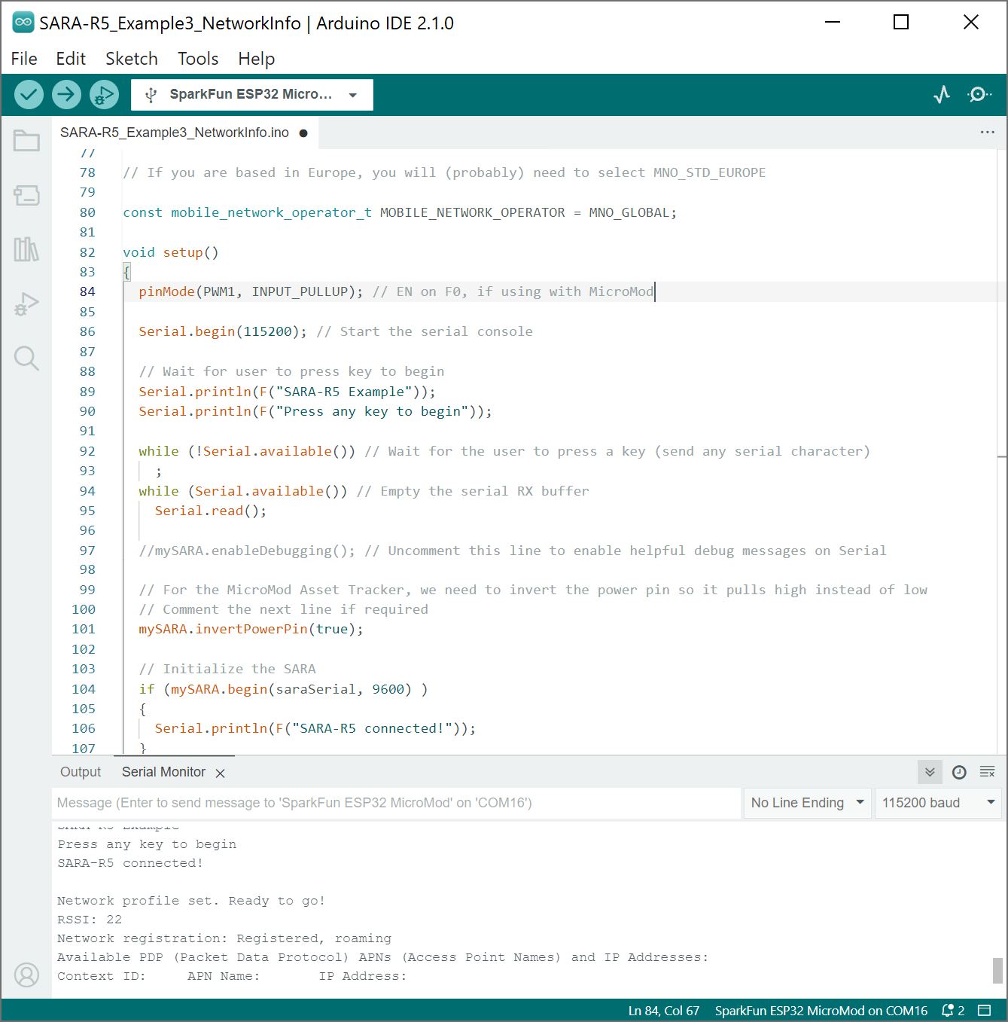
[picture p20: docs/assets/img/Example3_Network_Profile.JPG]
     <td></td>
    </tr>
  </table>
</div>

Depending on the output in the Serial Monitor, you may need to scroll down to view the Context ID, APN, and IP Address.

### Example 4 - Register Operator

Example 4 checks to see if the SARA-R5 is connected to a network and lets you register on a different network if available and if the SIM supports this. This example can also be used to list all the LTE operators the SARA-R5 can detect.

!!!note
    You can only connect to networks supported by your SIM card. Refer to your SIM card manufacturer's documentation for supported networks.

Open the example by navigating to **File** > **Examples** > **SparkFun u-blox SARA-R5 Arduino Library** > **SARA-R5_Example4_RegisterOperator**.

If you have not already, select your board in the Tools menu (in our case **SparkFun ESP32 MicroMod**) and the correct Port it enumerated on and click "Upload". After uploading the code, open the Serial Monitor with the baud rate set to **115200**. Wait for the blue NI LED to light up and then send a keyboard input.

<div style="text-align: center;">
  <table>
    <tr align="center">
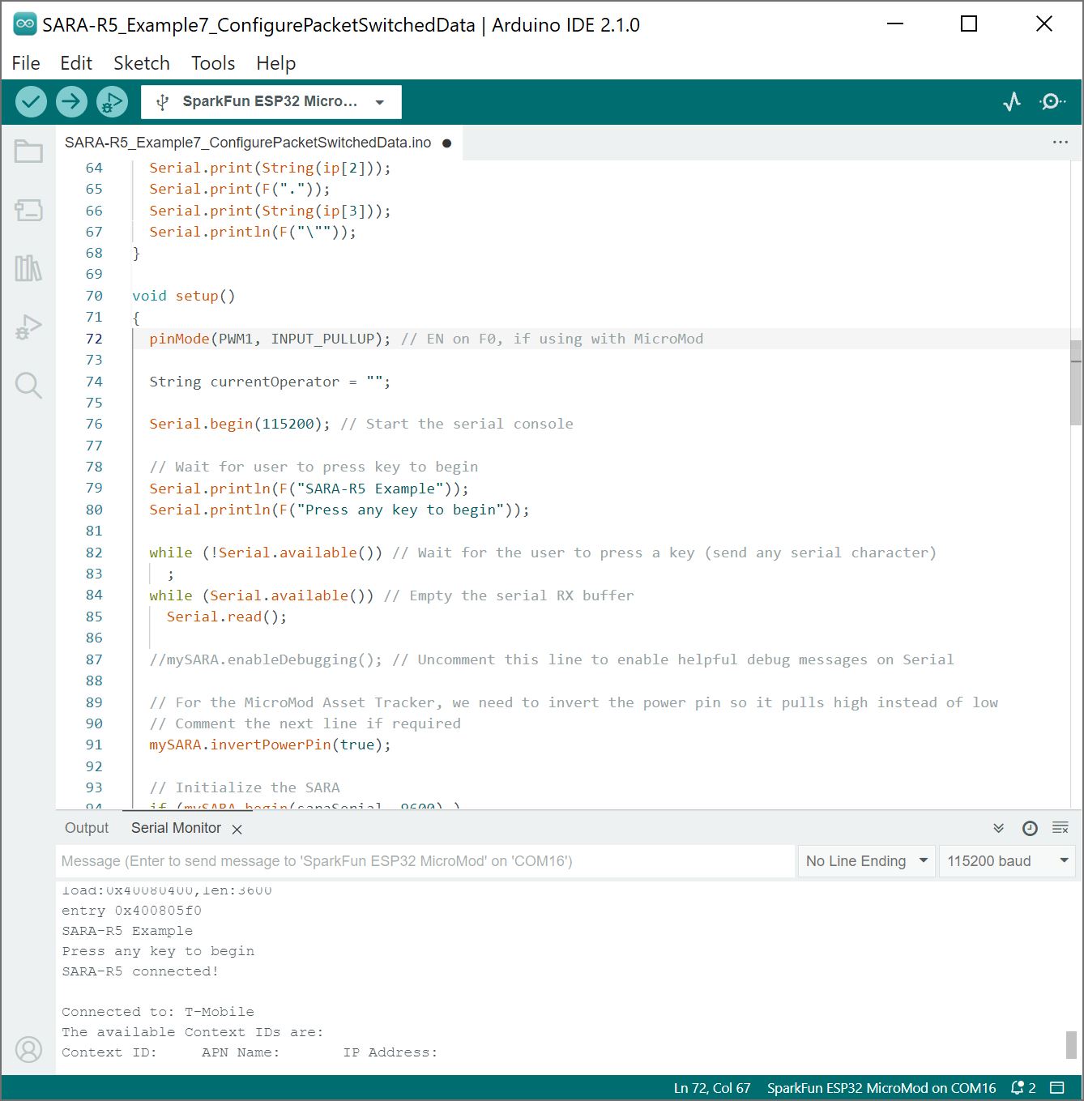
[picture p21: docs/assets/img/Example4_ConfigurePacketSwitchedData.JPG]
     <td></td>
    </tr>
  </table>
</div>

### Example 7 - Configure Packed Switched Data

Example 7 configures the "Context Identifier" for the mobile data connection. Make sure to go through this example to properly set up your SARA-R5 Context ID.

Open the example by navigating to **File** > **Examples** > **SparkFun u-blox SARA-R5 Arduino Library** > **SARA-R5_Example7_ConfigurePacketSwitchedData**.

If you have not already, select your board in the Tools menu (in our case **SparkFun ESP32 MicroMod**) and the correct Port it enumerated on and click "Upload". After uploading the code, open the Serial Monitor with the baud rate set to **115200**. Wait for the blue NI LED to light up and then send a keyboard input. Then follow the prompts to select the appropriate Context ID. You may see a few Context IDs so make sure to select one that looks correct (i.e. not a blank IP):

<div style="text-align: center;">
  <table>
    <tr align="center">
     <td></td>
    </tr>
  </table>
</div>

The code provides a warning that “deactivate profile failed”. We see this because the SARA needs to disconnect from a profile before it can connect to a new one, and in this case this failed because there was no profile active. Don't worry about this warning, it is just there for information. The example shows that our connection was successful by displaying the Internet Protocol (IP) address the SARA has been allocated by the service operator.

### Example 5 - Receive SMS

The fifth example demonstrates how to read and print any SMS text messages the SARA-R5 receives. The code checks whether the module is connected to an operator and will freeze if unsuccessful. If the code freezes here, wait and retry as it may be a connection issue with your network. Otherwise, return to Examples 3 and 4 to set up the Network Operator.

Open the example by navigating to **File** > **Examples** > **SparkFun u-blox SARA-R5 Arduino Library** > **SARA-R5_Example5_ReceiveSMS**.

The main loop accesses the message storage memory used for reading and deleting messages for data and prints the used and total number of memory locations in the message storage.

The code waits for any new messages to arrive and prints the Message Index (location), Status, Originator, Date and Time and then the message contents.

New messages are automatically marked as read once the code prints them. To force the code to print all the messages stored in the message memory, comment out this line:

    if (unread == "REC UNREAD")

If you have not already, select your board in the Tools menu (in our case **SparkFun ESP32 MicroMod**) and the correct Port it enumerated on and click "Upload". After uploading the code, open the Serial Monitor with the baud rate set to **115200**. Wait for the blue NI LED to light up and then send a keyboard input.

Assuming that you registered and activated your Hologram SIM card, log into your Hologram account. Head to the **Devices** and select the SIM card. Then select the **Messaging** tab and write message. Hit **Send SMS message** button.

<div style="text-align: center;">
  <table>
    <tr align="center">
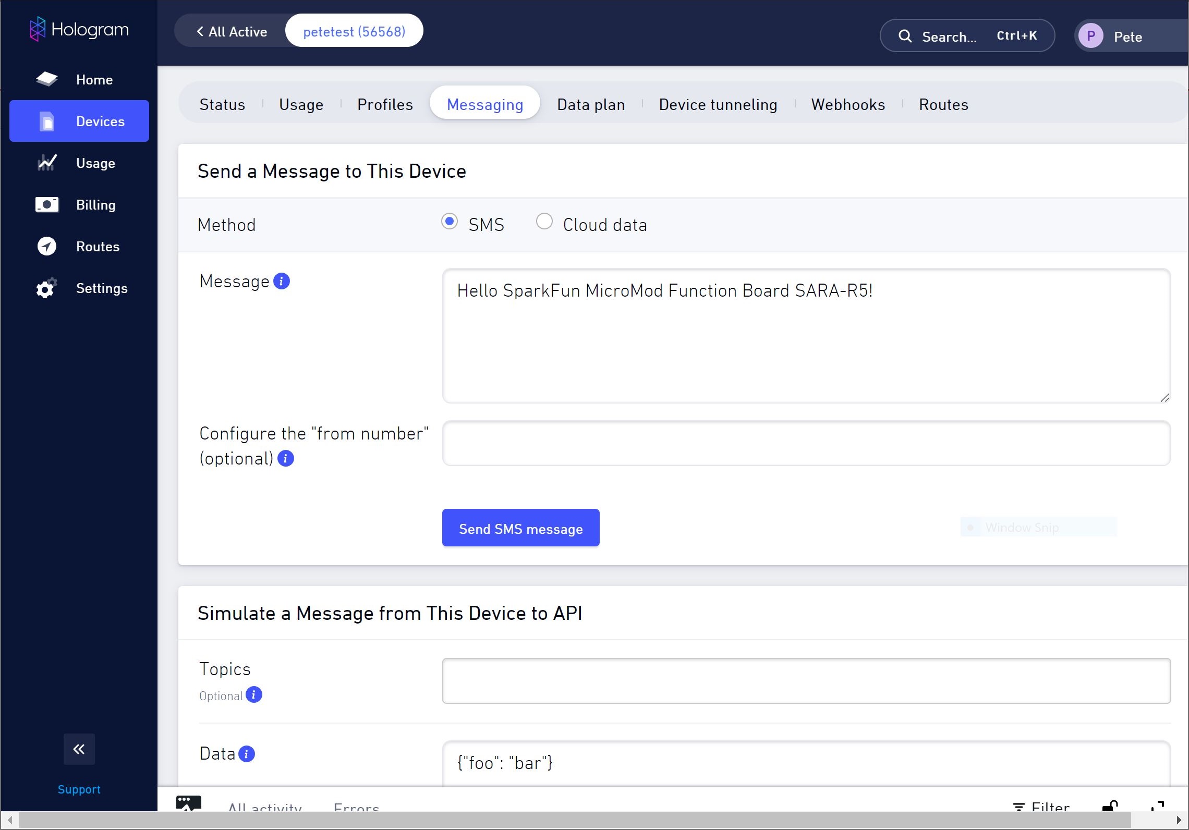
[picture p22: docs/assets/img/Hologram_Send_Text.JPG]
     <td></td>
    </tr>
  </table>
</div>

If all goes well, you will notice that the message was sent successfully!

<div style="text-align: center;">
  <table>
    <tr align="center">
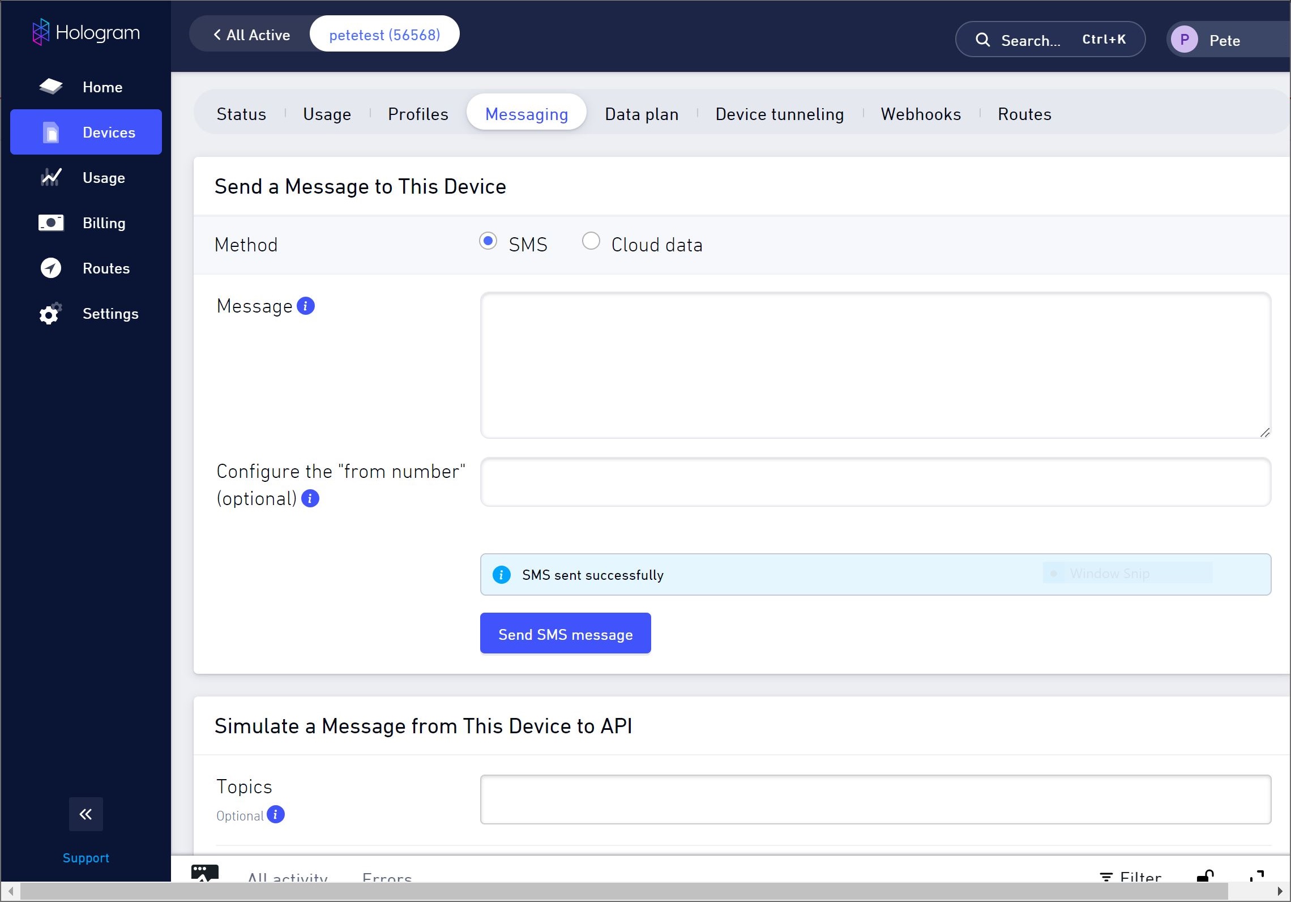
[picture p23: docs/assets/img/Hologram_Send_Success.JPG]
     <td></td>
    </tr>
  </table>
</div>

Head back to you Arduino Serial Monitor to view the message. You should see the message that was originally written in the Serial Monitor. Sweet!

<div style="text-align: center;">
  <table>
    <tr align="center">
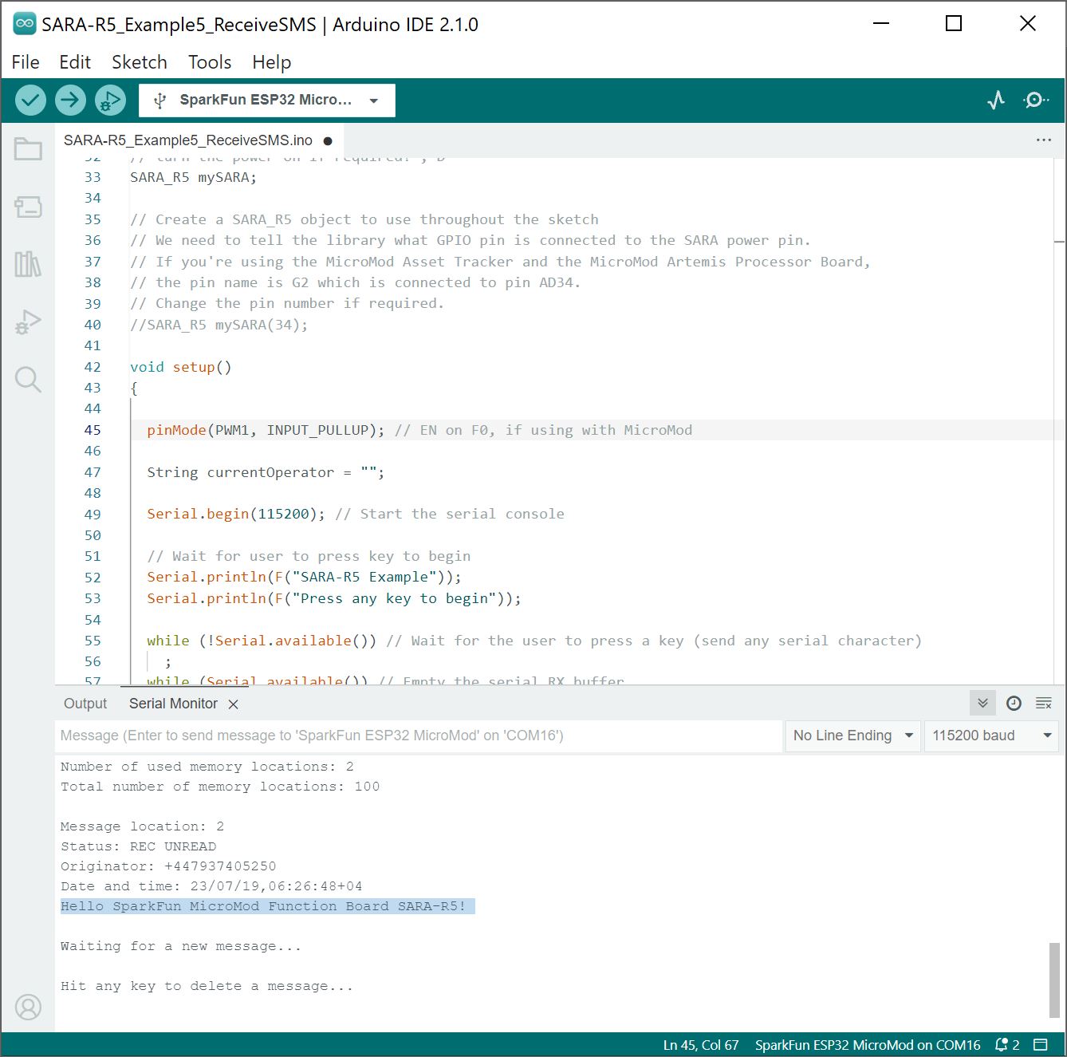
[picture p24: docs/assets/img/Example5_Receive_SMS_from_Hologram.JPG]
     <td></td>
    </tr>
  </table>
</div>

Before moving onto the next example, make sure to keep track of the "Originator". This is the number that is associated with the SIM card and your Hologram account.

### Example 6 - Send SMS

!!!note
    Depending on your network, you may have issues sending a SMS message to a smartphone. Even if you have the correct phone number entered and you receive a response that the message was sent successfully to your network, the service carrier may block the message from being sent to your smartphone. For more information, check out the article about [Troubleshooting Undelivered SMS Messages Sent To or From a Hologram Device](https://support.hologram.io/hc/en-us/articles/360047721933-Troubleshooting-undelivered-SMS-messages-sent-to-or-from-a-Hologram-device).

The sixth example sends SMS messages to another phone or LTE module from the SparkFun LTE GNSS Function Board - SARA-R5. The code prompts the user for the destination number and message contents.

Open the example by navigating to **File** > **Examples** > **SparkFun u-blox SARA-R5 Arduino Library** > **SARA-R5_Example6_SendSMS**.

If you have not already, select your board in the Tools menu (in our case **SparkFun ESP32 MicroMod**) and the correct Port it enumerated on and click "Upload". After uploading the code, open the Serial Monitor with the baud rate set to **115200**. Wait for the blue NI LED to light up and then send a keyboard input. Enter the message that you want to send and the destination number.

<div style="text-align: center;">
  <table>
    <tr align="center">
     <td></td>
    </tr>
  </table>
</div>

Assuming that you are using a Hologram SIM card, head back to your Hologram account. Expand the window where it says "All activity". You should see the original message that was sent from the SARA-R5!

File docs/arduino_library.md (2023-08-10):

!!! note

    ### Arduino IDE

    This example assumes you are using the latest version of the Arduino IDE on your desktop. If this is your first time using Arduino IDE and an library, please review the following tutorials.

    - [Installing the Arduino IDE](https://learn.sparkfun.com/tutorials/installing-arduino-ide)
    - [Installing an Arduino Library](https://learn.sparkfun.com/tutorials/installing-an-arduino-library)

    ### Board Definitions

    For the scope of this tutorial, we will be using the [MicroMod ESP32 Processor Board](https://learn.sparkfun.com/tutorials/micromod-esp32-processor-board-hookup-guide/software-setup-and-programming). If you have not installed a board definition before, please review the following tutorial as well.

    - [Installing Board Definitions in the Arduino IDE](https://learn.sparkfun.com/tutorials/installing-board-definitions-in-the-arduino-ide)

    ### USB-to-Serial Drivers

    The MicroMod ESP32 Processor Board also uses the CP2104 USB-to-Serial converter (other compatible Processor Boards may require a different driver). Users will need to install the SiLabs CP2104 Driver, which can be found here: [USB to UART Bridge VCP Driver](https://www.silabs.com/developers/usb-to-uart-bridge-vcp-drivers#software). Make sure to manually install the driver for the CP2104 with the following instructions. The driver that Windows auto-installs will not work with the auto-reset circuit on the board and cause serial uploads to fail.

    - [Windows VCP Driver (ZIP)](https://cdn.sparkfun.com/assets/learn_tutorials/8/5/2/CP210x_Universal_Windows_Driver.zip)
    - [MAC OSX VCP Driver (ZIP)](https://www.silabs.com/documents/public/software/Mac_OSX_VCP_Driver.zip)

    If applicable, make sure you are using the proper driver files for your CPU architecture. This is usually indicated by a folder or file name with "x86" for 32-bit processors or "x64" for 64-bit processors.

The SparkFun u-blox SARA-R5 Arduino Library provides a quick way to interact with the interfaces on the MicroMod LTE GNSS Function Board. Install the library through the Arduino Library Manager tool by searching for "**SparkFun u-blox SARA-R5**". Users who prefer to manually install the library can get it from the [GitHub Repository](https://github.com/sparkfun/SparkFun_u-blox_SARA-R5_Arduino_Library) or download the .ZIP by clicking the button below:

<div style="text-align: center"><a href="https://github.com/sparkfun/SparkFun_u-blox_SARA-R5_Arduino_Library/archive/refs/heads/master.zip" class="md-button">SparkFun SARA-R5 Arduino Library (ZIP)</a></div>

The library primarily works by associating a selection of AT Commands from the [Command Set Manual](https://cdn.sparkfun.com/assets/b/6/2/4/5/SARA-R5_ATCommands__UBX-19047455_.pdf) with standard Arduino functions to run automatically in a sketch. View the full list of AT Commands included in this library (along with all other available functions) in the [header file](https://github.com/sparkfun/SparkFun_u-blox_SARA-R5_Arduino_Library/blob/master/src/SparkFun_u-blox_SARA-R5_Arduino_Library.h). The list of included [AT Commands starts on line 93](https://github.com/sparkfun/SparkFun_u-blox_SARA-R5_Arduino_Library/blob/main/src/SparkFun_u-blox_SARA-R5_Arduino_Library.h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).

!!!note
    When using the MicroMod ESP32 Processor Board with the  **SparkFun_u-blox_SARA-R5_Arduino_Library** make sure to include the following line of code in the `setup()` function to enable the voltage regulator:

    <pre><code class="language-cpp">&nbsp;&nbsp;&nbsp;&nbsp;pinMode(PWM1, INPUT_PULLUP); // EN on F0 when using the ESP32 Processor Board</code></pre>

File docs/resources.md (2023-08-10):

Now that you've successfully got your SparkFun MicroMod LED GNSS Function Board - SARA-R5 up and running, it's time to incorporate it into your own project! For more information, check out the resources below:

* **LTE GNSS Function Board - SARA-R5 Documentation**
    * [Schematic](../assets/board_files/SparkFun_MicroMod_Function_SARA-R5_Schematic_v11.pdf)
    * [Eagle Files](../assets/board_files/SparkFun_MicroMod_Function_SARA-R5_V11.zip)
    * [Board Dimensions](../assets/board_files/SparkFun_MicroMod_LTE_GNSS_Function_Board_u-blox_SARA-R5_Board_Dimensions.png)
    * [Arduino Library](https://github.com/sparkfun/SparkFun_u-blox_SARA-R5_Arduino_Library)
    * [GitHub Hardware Repo](https://github.com/sparkfun/SparkFun_MicroMod_LTE_GNSS_Function_Board_u-blox_SARA-R5)
    * [SFE Product Showcase](https://www.youtube.com/watch?v=R37YaJobexs)
* **u-blox SARA-R5 LTE-M / NB-IoT Module Documentation**
    * [Datasheet](../assets/component_documentation/SARA-R5_DataSheet_UBX-19016638.pdf)
    * [AT Command Set](../assets/component_documentation/SARA-R5_ATCommands_UBX-19047455.pdf)
    * [System Integration Manual](../assets/component_documentation/SARA-R5_SysIntegrManual_UBX-19041356.pdf)
    * [Application Development Guide](../assets/component_documentation/SARA-R5-Application-Development_AppNote_(UBX-20009652).pdf)
    * [Internet Applications Development Guide](../assets/component_documentation/Internet-applications-development-guide_AppNote_UBX-20032566.pdf)
    * [GNSS Integration App Note](../assets/component_documentation/SARA-R5-R4-GNSS-Implementation_AppNote_UBX-20012413.pdf)
    * [Firmware Update App Note](../assets/component_documentation/SARA-R5-FW-Update_AppNote_(UBX-20033314).pdf)
* **MicroMod**
    * [Getting Started with MicroMod](https://learn.sparkfun.com/tutorials/getting-started-with-micromod)
    * [Designing with MicroMod](https://learn.sparkfun.com/tutorials/designing-with-micromod)
    * [MicroMod Info Page](https://www.sparkfun.com/micromod)
    * [MicroMod Forums](https://forum.sparkfun.com/viewforum.php?f=180)

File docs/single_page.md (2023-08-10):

---
hide:
  - navigation
  - toc
icon: fontawesome/solid/scroll
---

# Introduction
--8<-- "./docs/introduction.md"

# Hardware Overview
--8<-- "./docs/hardware_overview.md"

# Hardware Assembly
--8<-- "./docs/hardware_assembly.md"

# Software Setup
--8<-- "./docs/software_setup.md"

# Installing the Arduino Library
--8<-- "./docs/arduino_library.md"

# Arduino Examples
--8<-- "./docs/arduino_examples.md"

# Troubleshooting
--8<-- "./docs/troubleshooting.md"

# Resources
--8<-- "./docs/resources.md"

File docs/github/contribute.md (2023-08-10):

# Contribute: Help Fix our Mistake!
Spot something wrong? Feel free to contribute our open-source design and documentation. 

## Improve our Documentation
All of this documentation can be modified by you! Please help us make it better.

* These pages are contained in the [`docs` folder of the SparkFun MicroMod LTE GNSS Function Board repository](https://github.com/sparkfun/SparkFun_MicroMod_LTE_GNSS_Function_Board_u-blox_SARA-R5/tree/main/docs).

### Submit a Correction
1. Fork this repo
2. Add your corrections or improvements to the markdown file
3. File a pull request with your changes, and enjoy making the ~~words~~ ~~worlds~~ world a better place.
    * Once received, the documentation specialist will automatically be notified.
    * We will review your suggested improvements to make sure they are correct and fit within our documentation standards.

## Improve our Hardware Design
All of our designs are open-source! Please help us make it better.

* Our board design files are contained in the [`Hardware` folder of the SparkFun MicroMod LTE GNSS Function Board repository](https://github.com/sparkfun/SparkFun_MicroMod_LTE_GNSS_Function_Board_u-blox_SARA-R5/tree/main/Hardware).

### Submit a Design Improvement
1. Fork this repo
2. Add your design improvements
3. File a pull request with your changes, and enjoy making the ~~words~~ ~~worlds~~ world a better place.
    * Once received, the engineer in charge of the original design will automatically be notified.
    * We will review your suggested improvements, if they are within our board design standards and meet our product design requirements, we will flag these changes for our next board revision. *(Please note, that even if your suggestion is accepted, these changes may not be immediate. We may have to cycle through our current product inventory first.)*

## Contributors
Let's provided some recognition to the contributors for this project!

GitHub Contributors Image
<br>


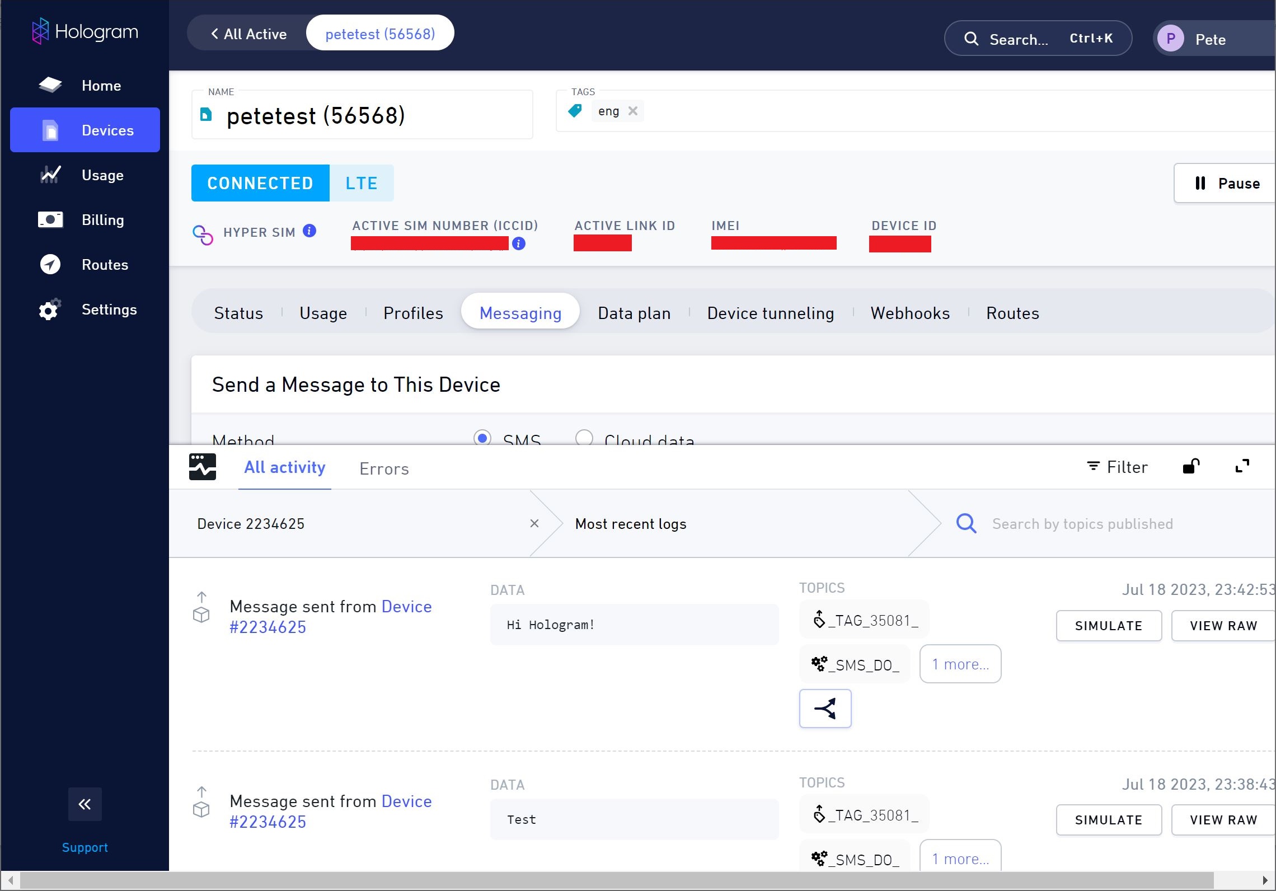
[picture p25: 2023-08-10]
docs/assets/img/Hologram_Receive_Success.JPG

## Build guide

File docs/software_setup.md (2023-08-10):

<!-- ## u-blox m-center

Interacting with the SARA-R5 over USB is a great way to get started with this breakout. For detailed instructions on installing and using the u-blox m-center software with your LTE GNSS Breakout - SARA-R5, head on over to the [MicroMod Asset Tracker Update Tool Hookup Guide](https://learn.sparkfun.com/tutorials/micromod-update-tool-hookup-guide/software-setup):

-->

## AT Command Set

For users who want to go right into directly manipulating the SARA-R5 using the AT Command Set, review the [AT Command Manual from u-blox](https://cdn.sparkfun.com/assets/b/6/2/4/5/SARA-R5_ATCommands__UBX-19047455_.pdf):

<div style="text-align: center"><a href="https://cdn.sparkfun.com/assets/b/6/2/4/5/SARA-R5_ATCommands__UBX-19047455_.pdf" class="md-button">SARA-R5 AT Commands Manual</a></div>

Read on to the next sections if you prefer to use the MicroMod LTE GNSS Function Board with the SparkFun u-blox SARA-R5 Arduino Library.

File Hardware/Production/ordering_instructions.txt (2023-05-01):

panel size, 128x137mm
PCB thickness, 0.8mm
number of layers, 4
controlled impedance, JLC7628
bevel, Gold Fingers + 45° Finger Chamfered
material, TG155
soldermask color, Red
silkscreen color, White
oz copper, 1oz
finish, ENIG
stencils, top
pcs per panel, 6
min trace width, 0.1270mm / 0.0050in
min drill size, 0.3048mm / 0.0120in
filename to layer stackup 1/2/3/4: GTL, GL2, GL3, GBL

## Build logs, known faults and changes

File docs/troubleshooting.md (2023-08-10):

This section outlines a few troubleshooting tips and common snags when using the SparkFun LTE GNSS FUnction Board - SARA-R5.

### LTE Network Availability

The SARA-R5 supports LTE-M and NB-IoT data communication for multi-regional use. Please check the LTE signal availability for your area before purchasing a SARA-R5 product and selecting an LTE service provider / operator.

### Data Connectivity

When working through the data connectivity examples, it is important that you run examples 13, 14 and 17 in order, before moving on to example 18 or 19. Each example builds on the last and together they configure the SARA’s data connection correctly.

### Arduino Debug Messages

If you run into any trouble using one of the Arduino examples, uncomment this line:

    assetTracker.enableDebugging(SERIAL_PORT);

This enables serial debugging to print out the full debug report from AT commands sent via functions in the library. Read through the data and search for matching error codes in Appendix A of the AT Command Reference manual to decipher the code.

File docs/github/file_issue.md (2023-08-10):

# Did we make a mistake?

Spot something wrong? Please let us know. 

!!! attention
    This is not where customers should seek assistance on a product. If you require technical assistance or have questions about a product that is not working as expected, please head over to the [SparkFun Technical Assistance](https://www.sparkfun.com/technical_assistance) page for some initial troubleshooting.<br /><br />

    <div style="text-align: center"><a href="https://www.sparkfun.com/technical_assistance" target="sfe_technical_assistance" class="md-button">SparkFun Technical Assistance Page</a></div>

    If you don't find what you need there, the <a href="https://forum.sparkfun.com/viewforum.php?f=180">SparkFun Forums: MicroMod</a> are a great place to find and ask for help. If this is your first visit, you'll need to <a href="https://forum.sparkfun.com/ucp.php?mode=register">create a Forum Account</a> to search product forums and post questions.<br /><br />

    <div style="text-align: center"><a href="https://forum.sparkfun.com/ucp.php?mode=register" class="md-button">Create New Forum Account</a>&nbsp;&nbsp;&nbsp;<a href="https://forum.sparkfun.com/viewforum.php?f=180" class="md-button md-button--primary">Log Into SparkFun Forums</a></div>

## Discrepancies in the Documentation

All of this documentation can be modified by you! Please help us make it better.

* The documentation files for these pages are contained in the [`docs` folder of the SparkFun MicroMod LTE GNSS Function Board repository](https://github.com/sparkfun/SparkFun_MicroMod_LTE_GNSS_Function_Board_u-blox_SARA-R5/tree/main/docs).

### Spot something wrong?
If a section of the documentation is incorrect, please [open an issue](https://github.com/sparkfun/SparkFun_MicroMod_LTE_GNSS_Function_Board_u-blox_SARA-R5/issues) and let us know.

### Do you have a suggested correction?
1. With a GitHub account, fork this repo
2. Add your correction(s) or improvement(s) to the markdown file(s)
3. File a pull request with your changes, and enjoy making the ~~words~~ ~~worlds~~ world a better place.
    * Once received, the documentation specialist will automatically be notified.
    * We will review your suggested improvement(s) to make sure they are correct and fit within our documentation standards.

## Problems in the Hardware Design

All of our designs are open-source! Please help us make it better.

* Our board design files are contained in the [`Hardware` folder of the SparkFun MicroMod LTE GNSS Function Board repository](https://github.com/sparkfun/SparkFun_MicroMod_LTE_GNSS_Function_Board_u-blox_SARA-R5/tree/main/Hardware).

### Does something not make sense?
If part of the design is confusing, please [open an issue](https://github.com/sparkfun/SparkFun_MicroMod_LTE_GNSS_Function_Board_u-blox_SARA-R5/issues) and let us know.

### Did we forget to include an important function of the board?
* Please keep in mind that we may intentionally exclude certain functions of the board to meet our product design requirements. *(For example, our Qwiic Micro boards are intended to fit on a small board layout and only use I<sup>2</sup>C communication; therefore, we may not have the SPI and interrupt pins available for users.)*
* If part of the board's functionality is missing, please [open an issue](https://github.com/sparkfun/SparkFun_MicroMod_LTE_GNSS_Function_Board_u-blox_SARA-R5/issues) and file a feature request.

### Do you wish to contribute directly to improving the board design?
1. With a GitHub account, Fork this repo
2. Add your design improvement(s)
3. File a pull request with your changes, and enjoy making the ~~words~~ ~~worlds~~ world a better place.
    * Once received, the engineer in charge of the original design will automatically be notified.
    * We will review your suggested improvement(s), if they are within our board design standards and meet our product design requirements, we will flag these changes for our next board revision. *(Please note, that even if your suggestion is accepted, these changes may not be immediate. We may have to cycle through our current product inventory first.)*

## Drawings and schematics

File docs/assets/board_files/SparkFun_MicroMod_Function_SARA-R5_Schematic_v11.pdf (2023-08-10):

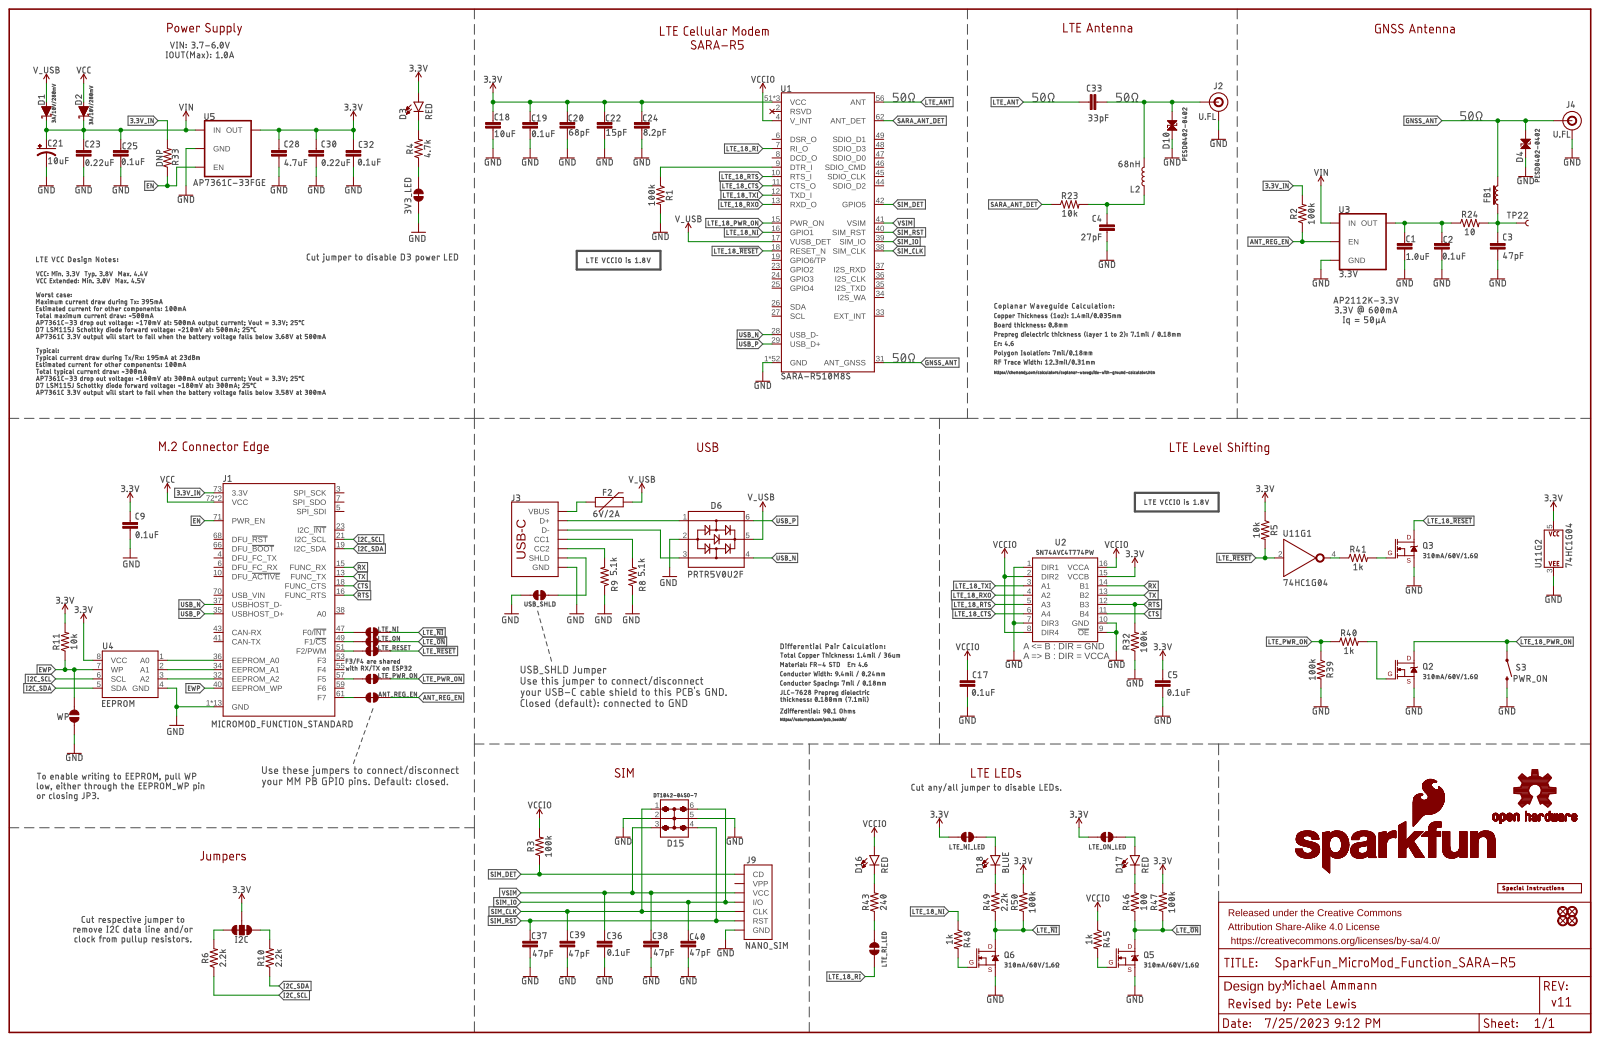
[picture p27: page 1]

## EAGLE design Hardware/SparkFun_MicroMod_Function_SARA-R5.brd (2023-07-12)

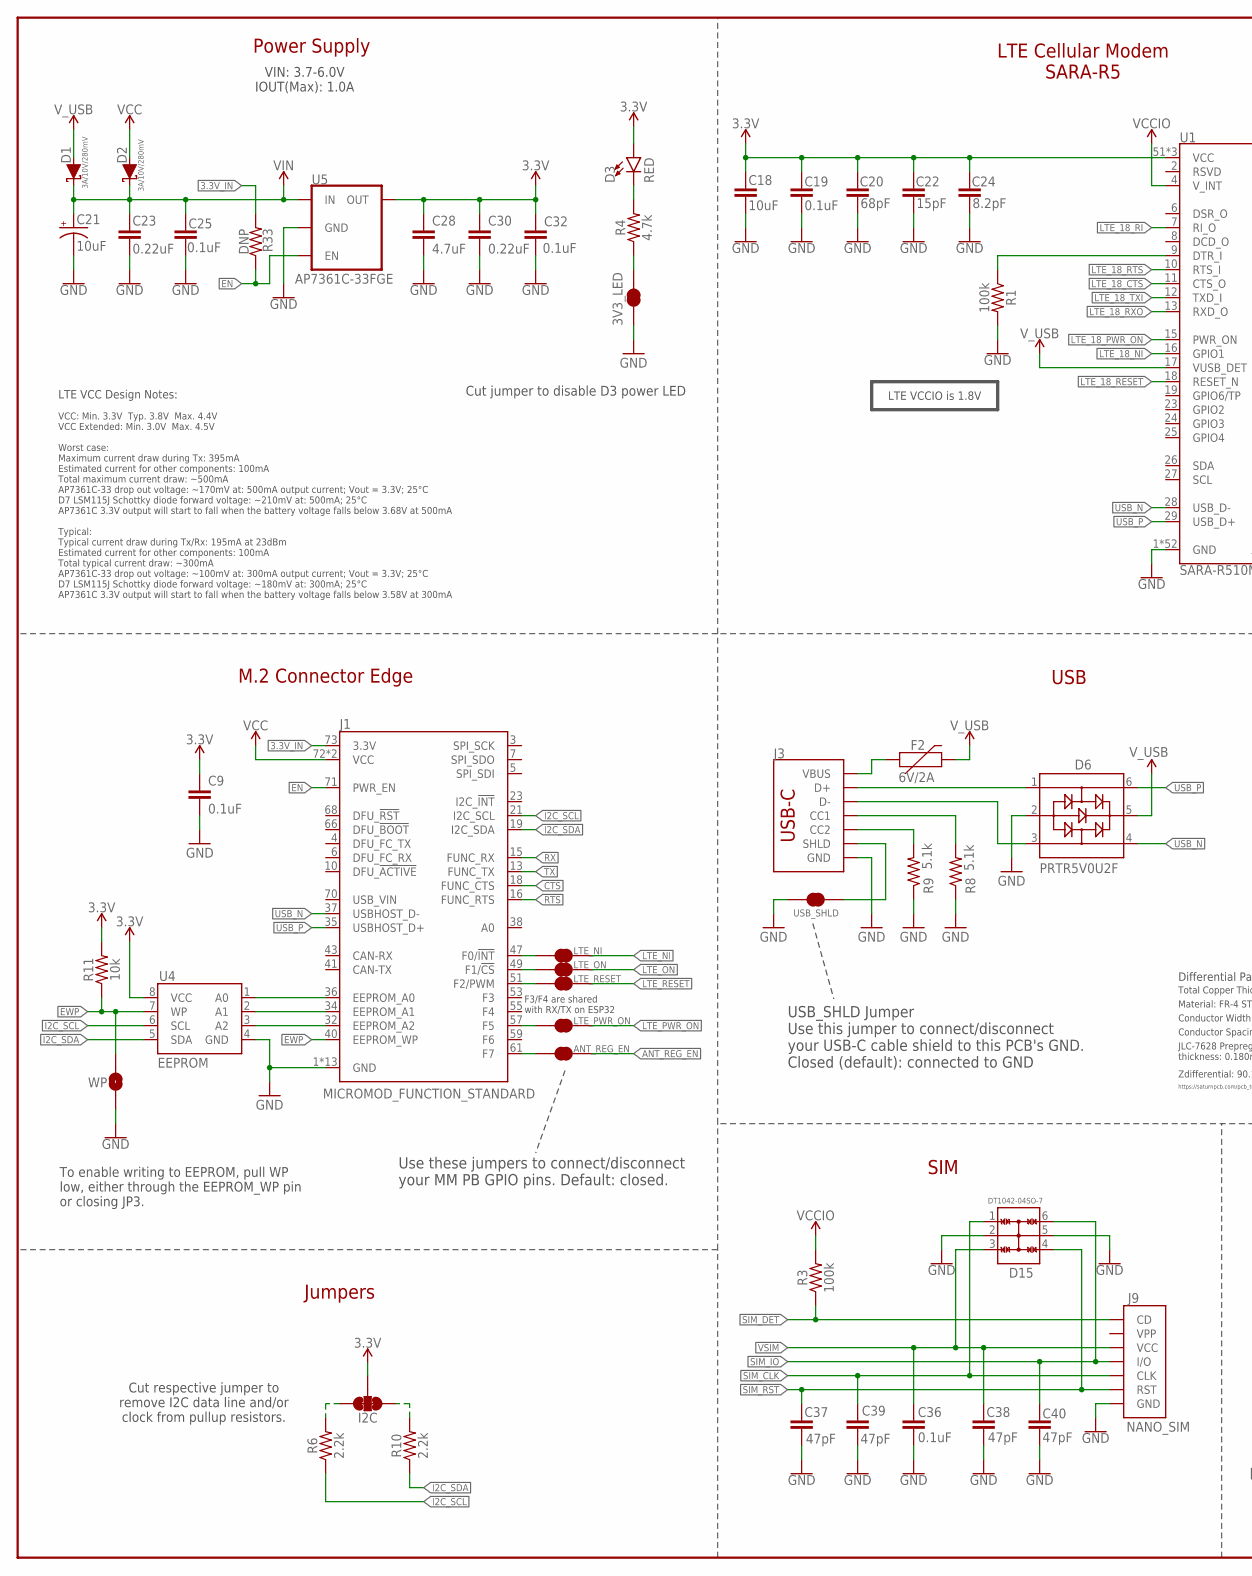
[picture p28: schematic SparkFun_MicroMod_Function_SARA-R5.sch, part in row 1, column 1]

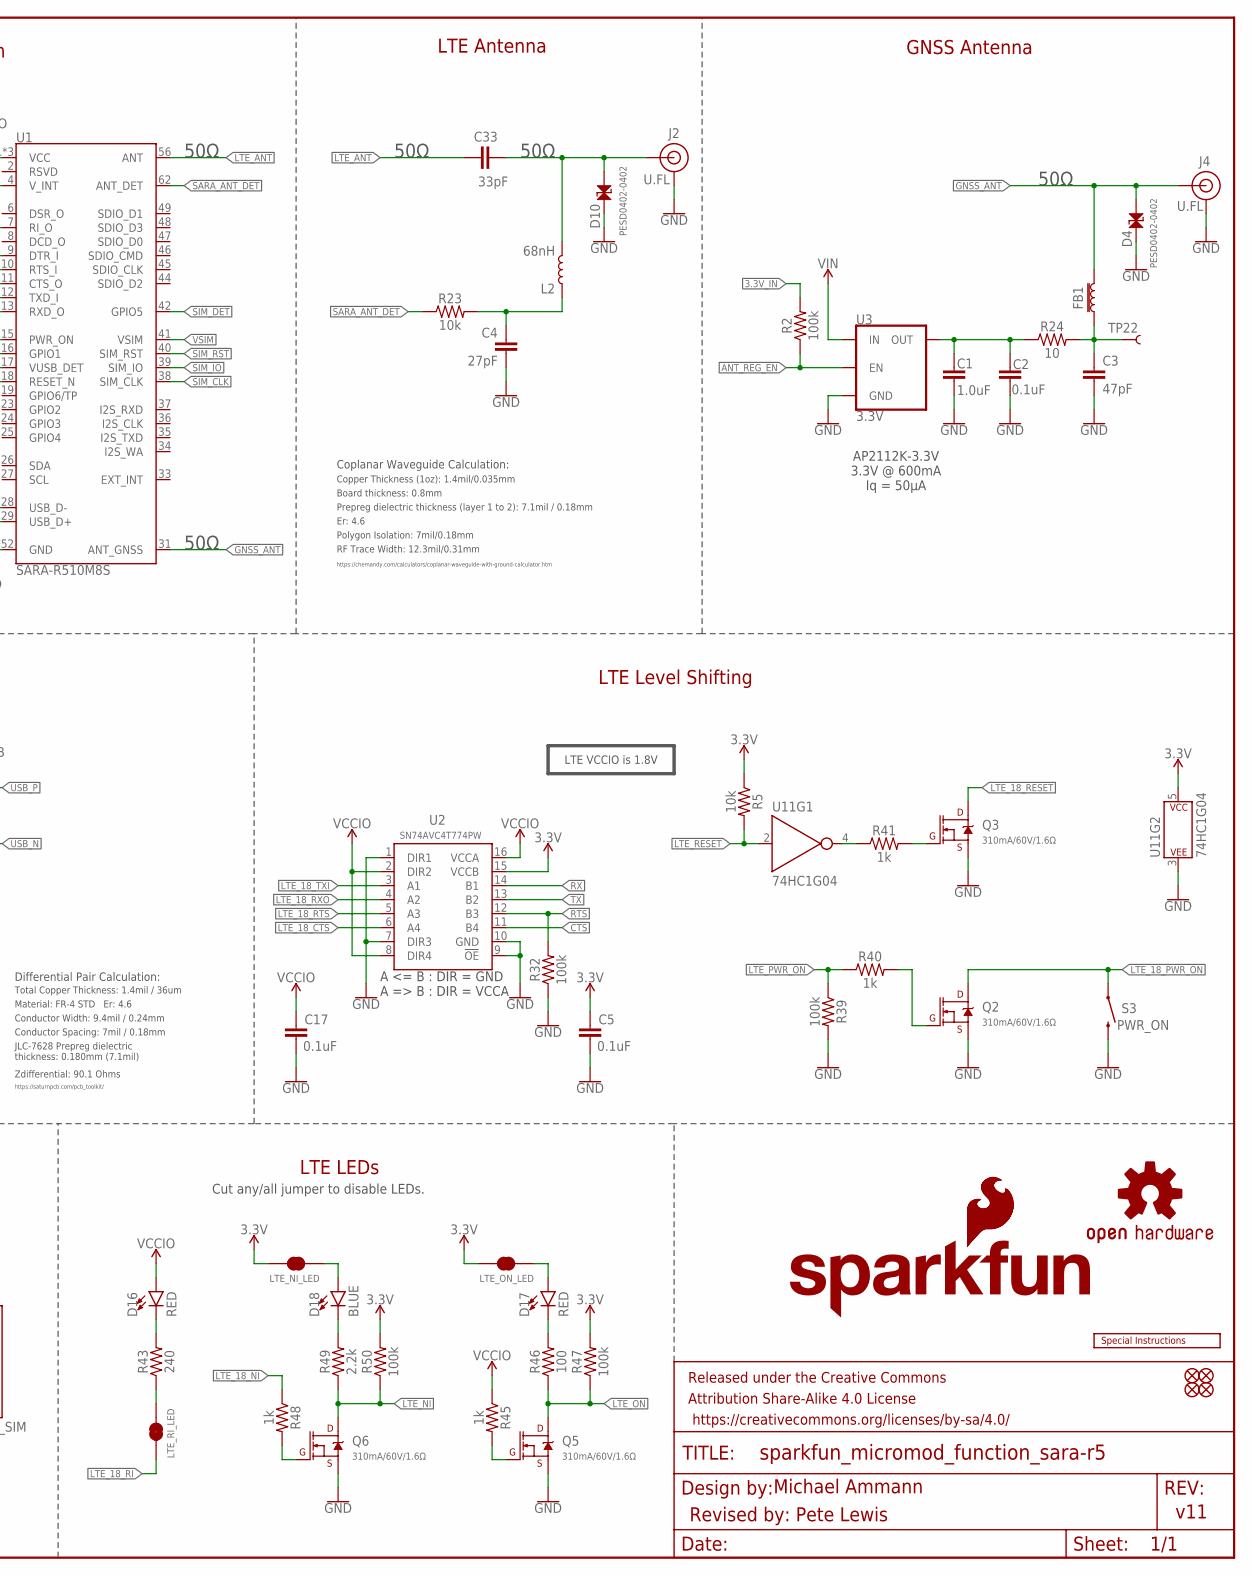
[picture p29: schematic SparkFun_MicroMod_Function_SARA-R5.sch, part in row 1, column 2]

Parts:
3V3_LED: JUMPER-SMT_2_NC_TRACE_SILK; SMT-JUMPER_2_NC_TRACE_SILK
ANT_REG_EN: JUMPER-SMT_2_NC_TRACE_SILK; SMT-JUMPER_2_NC_TRACE_SILK
C1: 1.0uF; 0603
C2, C5, C9, C17, C19, C25, C32, C36: 0.1uF; 0402-TIGHT
C3, C37, C38, C39, C40: 47pF; 0603
C4: 27pF; 0402
C18: 10uF; 0603
C20: 68pF; 0603
C21: 10uF; EIA3216
C22: 15pF; 0603
C23, C30: 0.22uF; 0603
C24: 8.2pF; 0603
C28: 4.7uF; 0603
C33: 33pF; 0402-TIGHT
D1, D2: 3A/10V/280mV; SOD-323
D3, D16, D17: RED; LED-0603
D4, D10: PESD0402-0402; 0402
D6: PRTR5V0U2F; SOT886
D15: DT1042-04SO-7; SOT23-6L
D18: BLUE; LED-0603
F2: 6V/2A; 1210
FB1: 30Ω/1.8A; 0603
FD1, FD2, FD3, FD4: FIDUCIALUFIDUCIAL; FIDUCIAL-MICRO
FRAME2: FRAME-LEDGER; CREATIVE_COMMONS
I2C: JUMPER-SMT_3_2-NC_TRACE_SILK; SMT-JUMPER_3_2-NC_TRACE_SILK
J1: MICROMOD_FUNCTION_STANDARD; M.2-CARD-E-22_FUNCTION_STANDARD
J2, J4: U.FL
J3: USB_C_2-LAYER_PADS; USB-C-16P-2LAYER-PADS
J9: NANO_SIM; NANO_SIM_PP
L2: 68nH; 0402_COILCRAFT
LOGO1: SFE_LOGO_NAME_FLAME.2_INCH; SFE_LOGO_NAME_FLAME_.2
LOGO2: SFE_LOGO_FLAME.2_INCH; SFE_LOGO_FLAME_.2
LOGO3: SPECIAL_INSTRUCTIONS-ORDERING; ORDERING_INSTRUCTIONS
LOGO4: OSHW-LOGOMINI; OSHW-LOGO-MINI
LTE_NI: JUMPER-SMT_2_NC_TRACE_SILK; SMT-JUMPER_2_NC_TRACE_SILK
LTE_NI_LED: JUMPER-SMT_2_NC_TRACE_SILK; SMT-JUMPER_2_NC_TRACE_SILK
LTE_ON: JUMPER-SMT_2_NC_TRACE_SILK; SMT-JUMPER_2_NC_TRACE_SILK
LTE_ON_LED: JUMPER-SMT_2_NC_TRACE_SILK; SMT-JUMPER_2_NC_TRACE_SILK
LTE_PWR_ON: JUMPER-SMT_2_NC_TRACE_SILK; SMT-JUMPER_2_NC_TRACE_SILK
LTE_RESET: JUMPER-SMT_2_NC_TRACE_SILK; SMT-JUMPER_2_NC_TRACE_SILK
LTE_RI_LED: JUMPER-SMT_2_NC_TRACE_SILK; SMT-JUMPER_2_NC_TRACE_SILK
Q2, Q3, Q5, Q6: 310mA/60V/1.6Ω; SOT323
R1, R2, R3, R32, R39, R47, R50: 100k; 0402-TIGHT
R4: 4.7k; 0402-TIGHT
R5, R11, R23: 10k; 0402-TIGHT
R6, R10, R49: 2.2k; 0402-TIGHT
R8, R9: 5.1k; 0402-TIGHT
R24: 10; 0603
R33: DNP; 0402-TIGHT
R40, R41, R45, R48: 1k; 0402-TIGHT
R43: 240; 0603
R46: 100; 0603
S3: PWR_ON; TACTILE_SWITCH_SMD_4.6X2.8MM
TP22: TEST-POINT3X4; PAD.03X.04
U1: SARA-R510M8S; SARA-LGA
U2: SN74AVC4T774PW; SOP65P640X120-16N
U3: 3.3V; SOT23-5
U4: EEPROM; SO08
U5: AP7361C-33FGE; UDFN-8
U11: 74HC1G04; SOT353
USB_SHLD: JUMPER-SMT_2_NC_TRACE_SILK; SMT-JUMPER_2_NC_TRACE_SILK
WP: JUMPER-SMT_2_NO_SILK; SMT-JUMPER_2_NO_SILK

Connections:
3.3V: C5.1, C9.1, C18.1, C19.1, C20.1, C22.1, C24.1, C28.1, C30.1, C32.1, D3.A, I2C.2, LTE_NI_LED.2, LTE_ON_LED.2, R5.1, R11.2, R47.2, R50.2, U1.51 (VCC), U1.52 (VCC), U1.53 (VCC), U2.15 (VCCB), U4.8 (VCC), U5.1 (OUT), U11.5 (P$V+)
3.3V_IN: J1.73 (3.3V), R2.2, R33.2
ANT_REG_EN: ANT_REG_EN.1, R2.1, U3.3 (EN)
CTS: J1.18 (FUNC_CTS), U2.11 (B4)
EN: J1.71 (PWR_EN), R33.1, U5.5 (EN)
EWP: J1.40 (EEPROM_WP), R11.1, U4.7 (WP), WP.2
GND: 3V3_LED.1, C1.2, C2.2, C3.2, C4.2, C5.2, C9.2, C17.2, C18.2, C19.2, C20.2, C21.-, C22.2, C23.2, C24.2, C25.2, C28.2, C30.2, C32.2, C36.1, C37.2, C38.1, C39.2, C40.1, D4.2, D6.2, D10.2, D15.2, D15.5, J1.1 (GND), J1.2 (GND), J1.8 (GND), J1.33 (GND), J1.39 (GND), J1.45 (GND), J1.75 (GND), J1.GND1 (GND), J1.GND2 (GND), J1.GND3 (GND), J1.GND4 (GND), J1.GND5 (GND), J1.GND6 (GND), J2.1 (GND), J2.2 (GND), J3.GND, J3.GND2 (GND), J4.1 (GND), J4.2 (GND), J9.A1 (GND), J9.A2 (GND), J9.A3 (GND), J9.A4 (GND), J9.C5 (GND), Q2.2 (S), Q3.2 (S), Q5.2 (S), Q6.2 (S), R1.2, R8.1, R9.1, R32.1, R39.2, S3.3 (2), S3.4 (2), U1.1 (GND), U1.3 (GND), U1.5 (GND), U1.14 (GND), U1.20 (GND), U1.21 (GND), U1.22 (GND), U1.30 (GND), U1.32 (GND), U1.43 (GND), U1.50 (GND), U1.54 (GND), U1.55 (GND), U1.57 (GND), U1.58 (GND), U1.59 (GND), U1.60 (GND), U1.61 (GND), U1.63 (GND), U1.64 (GND), U1.65 (GND), U1.66 (GND), U1.67 (GND), U1.68 (GND), U1.69 (GND), U1.70 (GND), U1.71 (GND), U1.72 (GND), U1.73 (GND), U1.74 (GND), U1.75 (GND), U1.76 (GND), U1.77 (GND), U1.78 (GND), U1.79 (GND), U1.80 (GND), U1.81 (GND), U1.82 (GND), U1.83 (GND), U1.84 (GND), U1.85 (GND), U1.86 (GND), U1.87 (GND), U1.88 (GND), U1.89 (GND), U1.90 (GND), U1.91 (GND), U1.92 (GND), U1.93 (GND), U1.94 (GND), U1.95 (GND), U1.96 (GND), U2.1 (DIR1), U2.7 (DIR3), U2.9 (!OE), U2.10 (GND), U3.2 (GND), U4.4 (GND), U5.4 (GND), U5.EP (GND), U11.3 (P$V-), USB_SHLD.2, WP.1
GNSS_ANT: D4.1, FB1.2, J4.FEED (SIGNAL), U1.31 (ANT_GNSS)
I2C_SCL: J1.21 (I2C_SCL), R6.1, U4.6 (SCL)
I2C_SDA: J1.19 (I2C_SDA), R10.1, U4.5 (SDA)
LTE_18_!RESET!: Q3.3 (D), U1.18 (RESET_N)
LTE_18_CTS: U1.11 (CTS_O), U2.6 (A4)
LTE_18_DTR: R1.1, U1.9 (DTR_I)
LTE_18_NI: R48.1, U1.16 (GPIO1)
LTE_18_PWR_ON: Q2.3 (D), S3.1, S3.2 (1), U1.15 (PWR_ON)
LTE_18_RI: LTE_RI_LED.2, U1.7 (RI_O)
LTE_18_RTS: U1.10 (RTS_I), U2.5 (A3)
LTE_18_RXO: U1.13 (RXD_O), U2.4 (A2)
LTE_18_TXI: U1.12 (TXD_I), U2.3 (A1)
LTE_!NI!: LTE_NI.1, Q6.3 (D), R49.1, R50.1
LTE_!ON!: LTE_ON.1, Q5.3 (D), R46.1, R47.1
LTE_!RESET!: LTE_RESET.1, R5.2, U11.2 (A)
LTE_ANT: C33.1, U1.56 (ANT)
LTE_PWR_ON: LTE_PWR_ON.1, R39.1, R40.1
unnamed: J1.36 (EEPROM_A0), U4.1 (A0)
unnamed: J3.A5 (CC1), R8.2
unnamed: J1.57 (F5), LTE_PWR_ON.2
unnamed: ANT_REG_EN.2, J1.61 (F7)
unnamed: J3.B5 (CC2), R9.2
unnamed: 3V3_LED.2, R4.1
unnamed: D3.C, R4.2
unnamed: J1.32 (EEPROM_A2), U4.3 (A2)
unnamed: J1.34 (EEPROM_A1), U4.2 (A1)
unnamed: D6.1, J3.A6 (D+), J3.B6 (D+)
unnamed: C33.2, D10.1, J2.FEED (SIGNAL), L2.P$2 (2)
unnamed: J1.47 (F0/!INT!), LTE_NI.2
unnamed: I2C.1, R10.2
unnamed: I2C.3, R6.2
unnamed: D6.3, J3.A7 (D-), J3.B7 (D-)
unnamed: J1.49 (F1/!CS!), LTE_ON.2
unnamed: J1.51 (F2/PWM), LTE_RESET.2
unnamed: C4.1, L2.P$1 (1), R23.2
unnamed: D18.A, LTE_NI_LED.1
unnamed: LTE_RI_LED.1, R43.1
unnamed: D17.A, LTE_ON_LED.1
unnamed: F2.1, J3.VBUS1 (VBUS), J3.VBUS2 (VBUS)
unnamed: C1.1, C2.1, R24.1, U3.5 (OUT)
unnamed: C3.1, FB1.1, R24.2, TP22.1
unnamed: Q2.1 (G), R40.2
unnamed: Q3.1 (G), R41.2
unnamed: R41.1, U11.4 (Y)
unnamed: D16.C, R43.2
unnamed: Q6.1 (G), R48.2
unnamed: D18.C, R49.2
unnamed: Q5.1 (G), R45.2
unnamed: D17.C, R46.2
RTS: J1.16 (FUNC_RTS), R32.2, U2.12 (B3)
RX: J1.15 (FUNC_RX), U2.14 (B1)
SARA_ANT_DET: R23.1, U1.62 (ANT_DET)
SHLD: J3.SHLD1 (SHLD), J3.SHLD2 (SHLD), J3.SHLD3 (SHLD), J3.SHLD4 (SHLD), USB_SHLD.1
SIM_CLK: C39.1, D15.1, J9.C3 (CLK), U1.38 (SIM_CLK)
SIM_DET: J9.CD, R3.1, U1.42 (GPIO5)
SIM_IO: C40.2, D15.6, J9.C7 (I/O), U1.39 (SIM_IO)
SIM_RST: C37.1, D15.4, J9.C2 (RST), U1.40 (SIM_RST)
TX: J1.13 (FUNC_TX), U2.13 (B2)
USB_N: D6.4, J1.37 (USBHOST_D-), U1.28 (USB_D-)
USB_P: D6.6, J1.35 (USBHOST_D+), U1.29 (USB_D+)
VCC: D2.A, J1.72 (VCC), J1.74 (VCC)
VCCIO: C17.1, D16.A, R3.2, R45.1, U1.4 (V_INT), U2.2 (DIR2), U2.8 (DIR4), U2.16 (VCCA)
VIN: C21.+, C23.1, C25.1, D1.C, D2.C, U3.1 (IN), U5.8 (IN)
VSIM: C36.2, C38.2, D15.3, J9.C1 (VCC), U1.41 (VSIM)
V_USB: D1.A, D6.5, F2.2, U1.17 (VUSB_DET)

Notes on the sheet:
Michael Ammann
v11
M.2 Connector Edge
Power Supply
Jumpers
Cut respective jumper to remove I2C data line and/or clock from pullup resistors.
To enable writing to EEPROM, pull WP low, either through the EEPROM_WP pin or closing JP3.
Cut jumper to disable D3 power LED
LTE VCC Design Notes:
VCC: Min. 3.3V Typ. 3.8V Max. 4.4V VCC Extended: Min. 3.0V Max. 4.5V Worst case: Maximum current draw during Tx: 395mA Estimated current for other components: 100mA Total maximum current draw: ~500mA AP7361C-33 drop out voltage: ~170mV at: 500mA output current; Vout = 3.3V; 25°C D7 LSM115J Schottky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
VIN: 3.7-6.0V IOUT(Max): 1.0A
LTE Cellular Modem SARA-R5
SIM
50Ω
LTE VCCIO is 1.8V
LTE Antenna
LTE LEDs
LTE Level Shifting
USB
F3/F4 are shared with RX/TX on ESP32
Revised by: Pete Lewis
GNSS Antenna
AP2112K-3.3V 3.3V @ 600mA Iq = 50µA
Material: FR-4 STD Er: 4.6
Total Copper Thickness: 1.4mil / 36um
Conductor Spacing: 7mil / 0.18mm
Conductor Width: 9.4mil / 0.24mm
JLC-7628 Prepreg dielectric thickness: 0.180mm (7.1mil)
https://saturnpcb.com/pcb_toolkit/
Differential Pair Calculation:
Zdifferential: 90.1 Ohms
USB_SHLD Jumper Use this jumper to connect/disconnect your USB-C cable shield to this PCB's GND. Closed (default): connected to GND
Board thickness: 0.8mm
Er: 4.6
Copper Thickness (1oz): 1.4mil/0.035mm
RF Trace Width: 12.3mil/0.31mm
Polygon Isolation: 7mil/0.18mm
Prepreg dielectric thickness (layer 1 to 2): 7.1mil / 0.18mm
https://chemandy.com/calculators/coplanar-waveguide-with-ground-calculator.htm
Coplanar Waveguide Calculation:

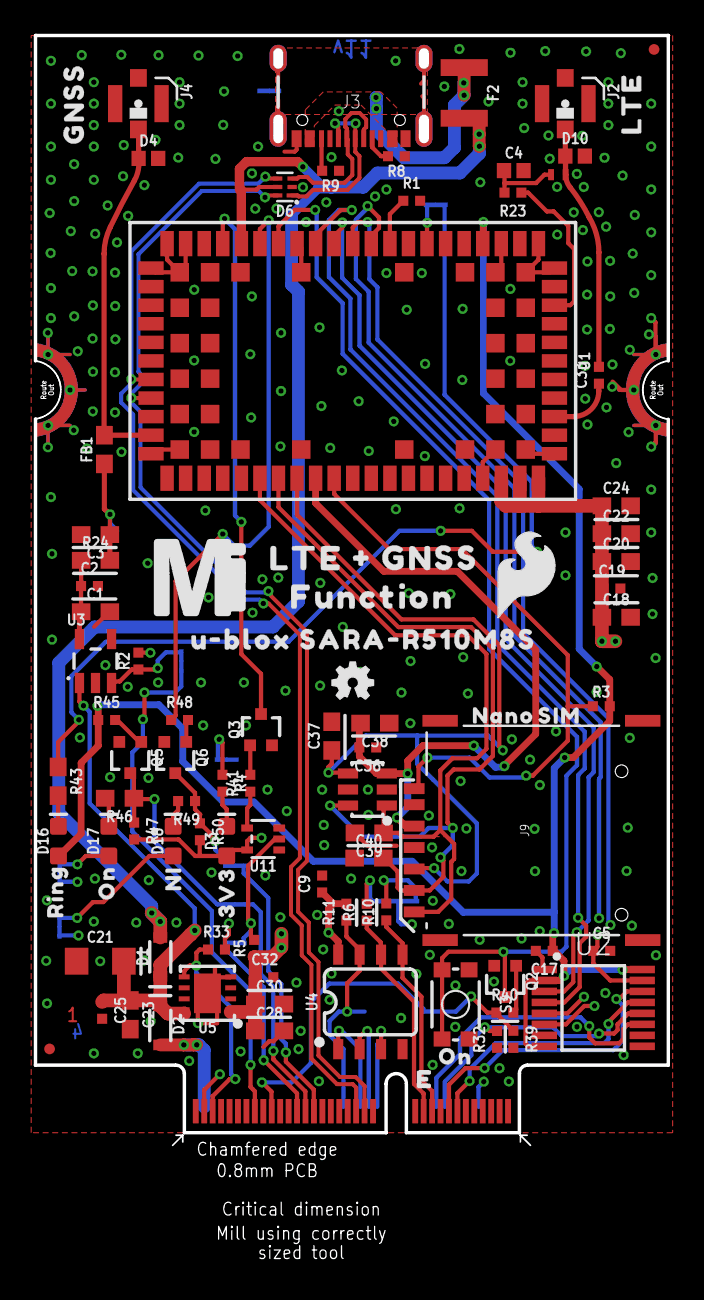
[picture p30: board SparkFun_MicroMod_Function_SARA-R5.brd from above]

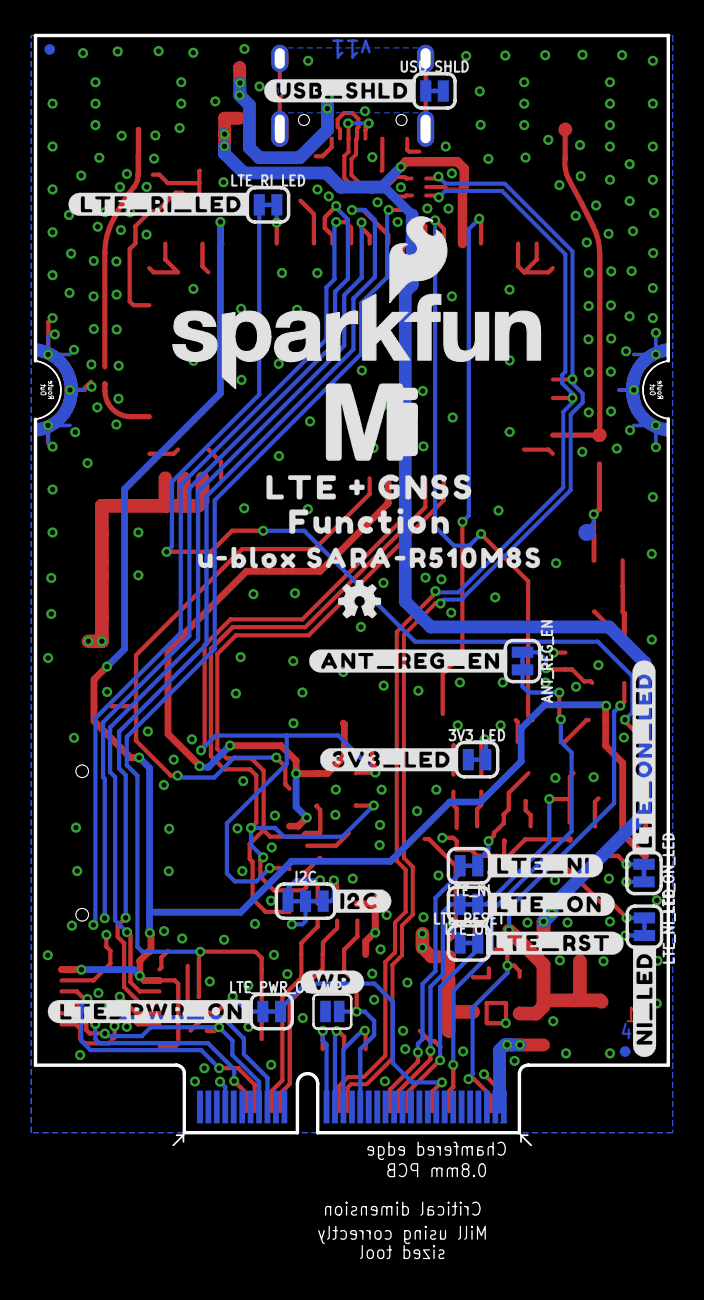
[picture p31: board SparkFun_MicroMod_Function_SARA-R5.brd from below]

Board: 4 copper layers, 37.5 x 65.8 mm, 129 parts (33 on the bottom side), 72 nets.

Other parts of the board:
LOGO6: OSHW-LOGOMINI; OSHW-LOGO-MINI
U$1: #I2C#0
U$2: #ANT_REG_EN#0
U$3, U$12: MICROMOD_MI_LOGO_1
U$4: #3V3_LED#0
U$5, U$31: ON0
U$6: #LTE_ON#2
U$7: #LTE_NI#2
U$8: #LTE_PWR_ON#1
U$9: #NI_LED#0
U$10: #WP#0
U$11, U$14: LTE_#_GNSS0
U$13, U$19: FUNCTION0
U$15, U$20: U#BLOX_SARA#R510M8S0
U$16: LTE0
U$17: GNSS0
U$18: NANO0
U$21: #USB_SHLD#0
U$22: #LTE_RI_LED#0
U$23: #LTE_RST#0
U$24: #LTE_ON_LED#0
U$29: NI0
U$57: 3V34
U$80: RING0
U$126: SIM0

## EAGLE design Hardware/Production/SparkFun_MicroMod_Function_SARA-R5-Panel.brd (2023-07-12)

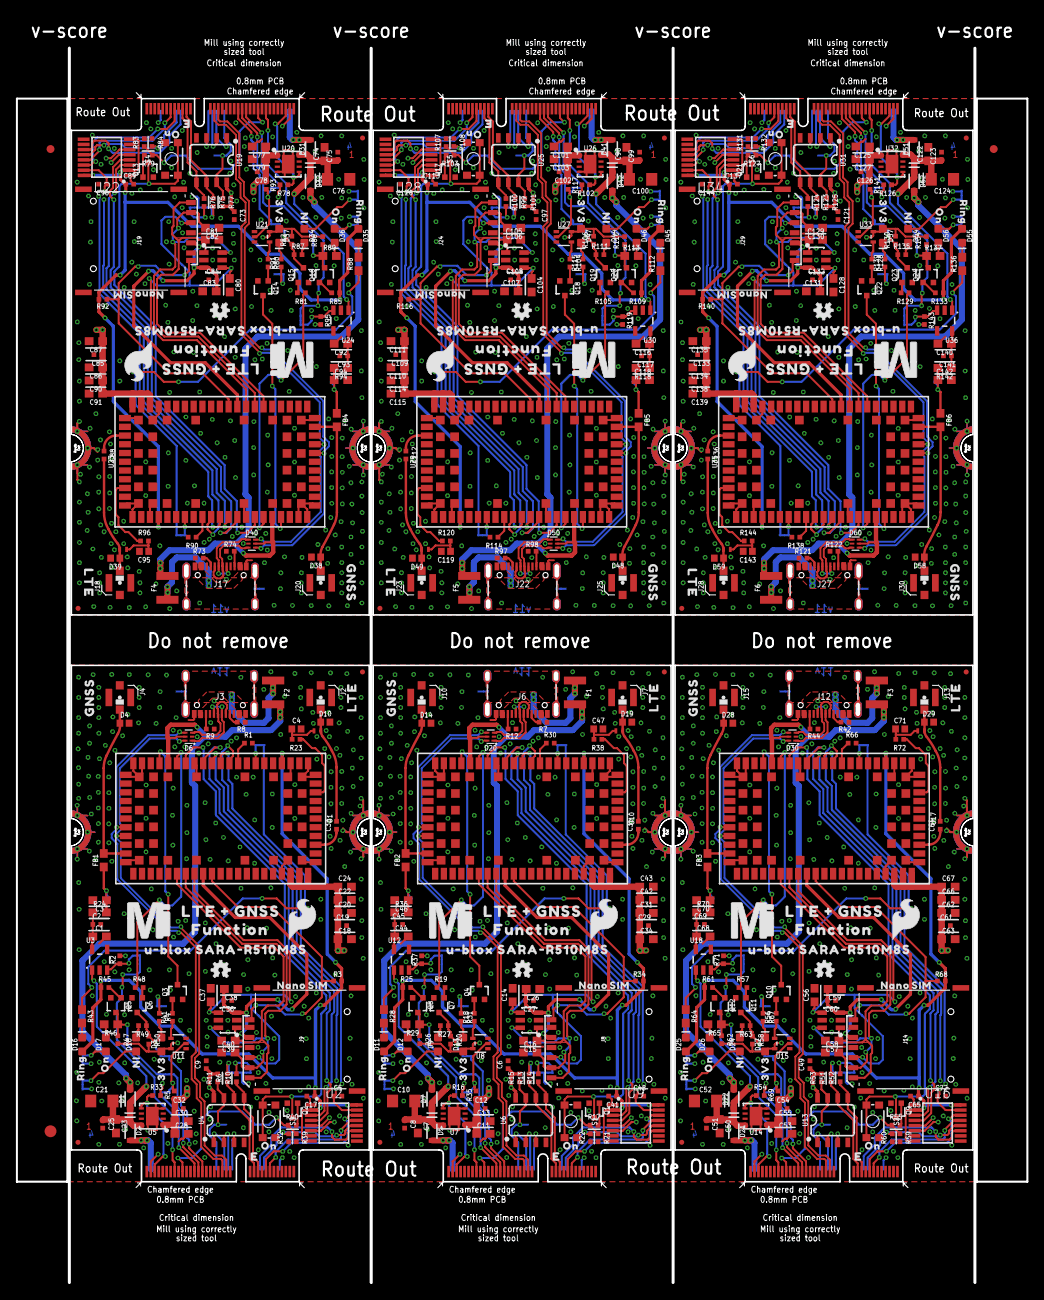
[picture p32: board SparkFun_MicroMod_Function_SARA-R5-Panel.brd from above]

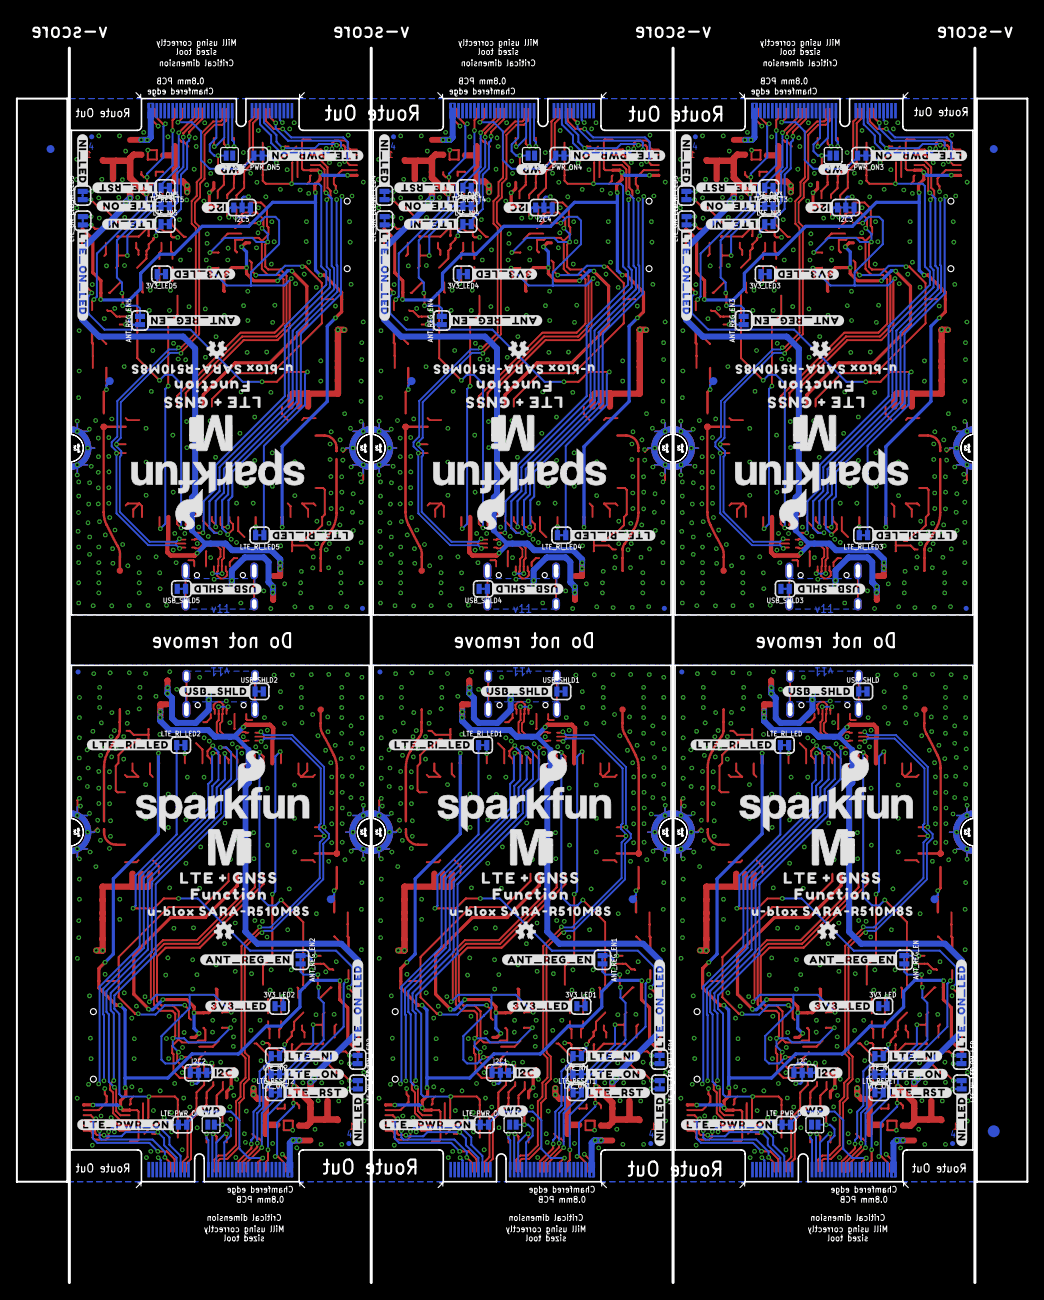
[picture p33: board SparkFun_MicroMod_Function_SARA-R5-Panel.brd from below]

Board: 4 copper layers, 127.2 x 155.4 mm, 768 parts (201 on the bottom side), 432 nets.

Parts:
3V3_LED, 3V3_LED1, 3V3_LED2, 3V3_LED3, 3V3_LED4, 3V3_LED5: JUMPER-SMT_2_NC_TRACE_SILK; SMT-JUMPER_2_NC_TRACE_SILK
ANT_REG_EN, ANT_REG_EN1, ANT_REG_EN2, ANT_REG_EN3, ANT_REG_EN4, ANT_REG_EN5: JUMPER-SMT_2_NC_TRACE_SILK; SMT-JUMPER_2_NC_TRACE_SILK
C1, C44, C68, C92, C116, C140: 1.0uF; 0603
C2, C5, C6, C8, C9, C12, C17, C19, C25, C27, C29, C32, C36, C41, C45, C48, C49, C51, C54, C60, C61, C65, C69, C72, C73, C75, C78, C84, C85, C89, C93, C96, C97, C99, C102, C108, C109, C113, C117, C120, C121, C123, C126, C132, C133, C137, C141, C144: 0.1uF; 0402-TIGHT
C3, C14, C15, C16, C26, C37, C38, C39, C40, C46, C56, C57, C58, C59, C70, C80, C81, C82, C83, C94, C104, C105, C106, C107, C118, C128, C129, C130, C131, C142: 47pF; 0603
C4, C47, C71, C95, C119, C143: 27pF; 0402
C7, C13, C23, C30, C50, C55, C74, C79, C98, C103, C122, C127: 0.22uF; 0603
C10, C21, C52, C76, C100, C124: 10uF; EIA3216
C11, C28, C53, C77, C101, C125: 4.7uF; 0603
C18, C34, C63, C87, C111, C135: 10uF; 0603
C20, C31, C62, C86, C110, C134: 68pF; 0603
C22, C42, C66, C90, C114, C138: 15pF; 0603
C24, C43, C67, C91, C115, C139: 8.2pF; 0603
C33, C35, C64, C88, C112, C136: 33pF; 0402-TIGHT
D1, D2, D5, D7, D21, D22, D31, D32, D41, D42, D51, D52: 3A/10V/280mV; SOD-323
D3, D11, D12, D13, D16, D17, D25, D26, D27, D35, D36, D37, D45, D46, D47, D55, D56, D57: RED; LED-0603
D4, D10, D14, D19, D28, D29, D38, D39, D48, D49, D58, D59: PESD0402-0402; 0402
D6, D20, D30, D40, D50, D60: PRTR5V0U2F; SOT886
D8, D15, D23, D33, D43, D53: DT1042-04SO-7; SOT23-6L
D9, D18, D24, D34, D44, D54: BLUE; LED-0603
E$1, E$2, E$3, E$4: FIDUCIAL-1X2
E$5, E$6: FIDUCIAL-1.5X3
F1, F2, F3, F4, F5, F6: 6V/2A; 1210
FB1, FB2, FB3, FB4, FB5, FB6: 30Ω/1.8A; 0603
FD1, FD2, FD3, FD4, FD5, FD6, FD7, FD8, FD9, FD10, FD11, FD12, FD13, FD14, FD15, FD16, FD17, FD18, FD19, FD20, FD21, FD22, FD23, FD24: FIDUCIALUFIDUCIAL; FIDUCIAL-MICRO
I2C, I2C1, I2C2, I2C3, I2C4, I2C5: JUMPER-SMT_3_2-NC_TRACE_SILK; SMT-JUMPER_3_2-NC_TRACE_SILK
J1, J5, J11, J16, J21, J26: MICROMOD_FUNCTION_STANDARD; M.2-CARD-E-22_FUNCTION_STANDARD
J2, J4, J7, J10, J13, J15, J18, J20, J23, J25, J28, J30: U.FL
J3, J6, J12, J17, J22, J27: USB-C-16P-2LAYER-PADS
J8, J9, J14, J19, J24, J29: NANO_SIM; NANO_SIM_PP
L1, L2, L3, L4, L5, L6: 68nH; 0402_COILCRAFT
LOGO1, LOGO3, LOGO9, LOGO13, LOGO17, LOGO21: SFE_LOGO_NAME_FLAME.2_INCH; SFE_LOGO_NAME_FLAME_.2
LOGO2, LOGO5, LOGO10, LOGO14, LOGO18, LOGO22: SFE_LOGO_FLAME.2_INCH; SFE_LOGO_FLAME_.2
LOGO4, LOGO6, LOGO7, LOGO8, LOGO11, LOGO12, LOGO15, LOGO16, LOGO19, LOGO20, LOGO23, LOGO24: OSHW-LOGOMINI; OSHW-LOGO-MINI
LTE_NI, LTE_NI1, LTE_NI2, LTE_NI3, LTE_NI4, LTE_NI5: JUMPER-SMT_2_NC_TRACE_SILK; SMT-JUMPER_2_NC_TRACE_SILK
LTE_NI_LED, LTE_NI_LED1, LTE_NI_LED2, LTE_NI_LED3, LTE_NI_LED4, LTE_NI_LED5: JUMPER-SMT_2_NC_TRACE_SILK; SMT-JUMPER_2_NC_TRACE_SILK
LTE_ON, LTE_ON1, LTE_ON2, LTE_ON3, LTE_ON4, LTE_ON5: JUMPER-SMT_2_NC_TRACE_SILK; SMT-JUMPER_2_NC_TRACE_SILK
LTE_ON_LED, LTE_ON_LED1, LTE_ON_LED2, LTE_ON_LED3, LTE_ON_LED4, LTE_ON_LED5: JUMPER-SMT_2_NC_TRACE_SILK; SMT-JUMPER_2_NC_TRACE_SILK
LTE_PWR_ON, LTE_PWR_ON1, LTE_PWR_ON2, LTE_PWR_ON3, LTE_PWR_ON4, LTE_PWR_ON5: JUMPER-SMT_2_NC_TRACE_SILK; SMT-JUMPER_2_NC_TRACE_SILK
LTE_RESET, LTE_RESET1, LTE_RESET2, LTE_RESET3, LTE_RESET4, LTE_RESET5: JUMPER-SMT_2_NC_TRACE_SILK; SMT-JUMPER_2_NC_TRACE_SILK
LTE_RI_LED, LTE_RI_LED1, LTE_RI_LED2, LTE_RI_LED3, LTE_RI_LED4, LTE_RI_LED5: JUMPER-SMT_2_NC_TRACE_SILK; SMT-JUMPER_2_NC_TRACE_SILK
Q1, Q2, Q3, Q4, Q5, Q6, Q7, Q8, Q9, Q10, Q11, Q12, Q13, Q14, Q15, Q16, Q17, Q18, Q19, Q20, Q21, Q22, Q23, Q24: 310mA/60V/1.6Ω; SOT323
R1, R2, R3, R20, R21, R22, R26, R30, R32, R34, R37, R39, R47, R50, R58, R59, R60, R62, R66, R68, R71, R82, R83, R84, R86, R90, R92, R95, R106, R107, R108, R110, R114, R116, R119, R130, R131, R132, R134, R138, R140, R143: 100k; 0402-TIGHT
R4, R31, R67, R91, R115, R139: 4.7k; 0402-TIGHT
R5, R11, R15, R23, R35, R38, R53, R69, R72, R77, R93, R96, R101, R117, R120, R125, R141, R144: 10k; 0402-TIGHT
R6, R10, R13, R14, R27, R49, R51, R52, R63, R75, R76, R87, R99, R100, R111, R123, R124, R135: 2.2k; 0402-TIGHT
R7, R8, R9, R12, R42, R44, R73, R74, R97, R98, R121, R122: 5.1k; 0402-TIGHT
R16, R33, R54, R78, R102, R126: DNP; 0402-TIGHT
R17, R18, R19, R25, R40, R41, R45, R48, R55, R56, R57, R61, R79, R80, R81, R85, R103, R104, R105, R109, R127, R128, R129, R133: 1k; 0402-TIGHT
R24, R36, R70, R94, R118, R142: 10; 0603
R28, R43, R64, R88, R112, R136: 240; 0603
R29, R46, R65, R89, R113, R137: 100; 0603
S1, S2, S3, S4, S5, S6: PWR_ON; TACTILE_SWITCH_SMD_4.6X2.8MM
TP1, TP2, TP3, TP4, TP5, TP22: TEST-POINT3X4; PAD.03X.04
U1, U10, U17, U23, U29, U35: SARA-R510M8S; SARA-LGA
U2, U9, U16, U22, U28, U34: SN74AVC4T774PW; SOP65P640X120-16N
U3, U12, U18, U24, U30, U36: 3.3V; SOT23-5
U4, U6, U13, U19, U25, U31: EEPROM; SO08
U5, U7, U14, U20, U26, U32: AP7361C-33FGE; UDFN-8
U8, U11, U15, U21, U27, U33: 74HC1G04; SOT353
U$1, U$50, U$81, U$110, U$140, U$169: #I2C#0
U$2, U$48, U$78, U$108, U$138, U$167: #ANT_REG_EN#0
U$3, U$12, U$35, U$36, U$65, U$66, U$95, U$96, U$124, U$125, U$154, U$155: MICROMOD_MI_LOGO_1
U$4, U$49, U$79, U$109, U$139, U$168: #3V3_LED#0
U$5, U$27, U$31, U$34, U$59, U$64, U$89, U$94, U$118, U$123, U$148, U$153: ON0
U$6, U$38, U$68, U$98, U$128, U$157: #LTE_ON#2
U$7, U$39, U$69, U$99, U$129, U$158: #LTE_NI#2
U$8, U$37, U$67, U$97, U$127, U$156: #LTE_PWR_ON#1
U$9, U$54, U$85, U$114, U$144, U$173: #NI_LED#0
U$10, U$25, U$56, U$87, U$116, U$146: #WP#0
U$11, U$14, U$40, U$45, U$70, U$75, U$100, U$105, U$130, U$135, U$159, U$164: LTE_#_GNSS0
U$13, U$19, U$41, U$46, U$71, U$76, U$101, U$106, U$131, U$136, U$160, U$165: FUNCTION0
U$15, U$20, U$42, U$47, U$72, U$77, U$102, U$107, U$132, U$137, U$161, U$166: U#BLOX_SARA#R510M8S0
U$16, U$43, U$73, U$103, U$133, U$162: LTE0
U$17, U$44, U$74, U$104, U$134, U$163: GNSS0
U$18, U$32, U$62, U$92, U$121, U$151: NANO0
U$21, U$51, U$82, U$111, U$141, U$170: #USB_SHLD#0
U$22, U$52, U$83, U$112, U$142, U$171: #LTE_RI_LED#0
U$23, U$53, U$84, U$113, U$143, U$172: #LTE_RST#0
U$24, U$55, U$86, U$115, U$145, U$174: #LTE_ON_LED#0
U$26, U$29, U$58, U$88, U$117, U$147: NI0
U$28, U$57, U$60, U$90, U$119, U$149: 3V34
U$30, U$61, U$80, U$91, U$120, U$150: RING0
U$33, U$63, U$93, U$122, U$126, U$152: SIM0
USB_SHLD, USB_SHLD1, USB_SHLD2, USB_SHLD3, USB_SHLD4, USB_SHLD5: JUMPER-SMT_2_NC_TRACE_SILK; SMT-JUMPER_2_NC_TRACE_SILK
WP, WP1, WP2, WP3, WP4, WP5: SMT-JUMPER_2_NO_SILK

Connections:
3.3V: C5.1, C9.1, C18.1, C19.1, C20.1, C22.1, C24.1, C28.1, C30.1, C32.1, D3.A, I2C.2, LTE_NI_LED.2, LTE_ON_LED.2, R5.1, R11.2, R47.2, R50.2, U1.51, U1.52, U1.53, U2.15, U4.8, U5.1, U11.5
3.3V1: C6.1, C11.1, C12.1, C13.1, C29.1, C31.1, C34.1, C42.1, C43.1, C48.1, D13.A, I2C1.2, LTE_NI_LED1.2, LTE_ON_LED1.2, R15.2, R20.2, R26.2, R35.1, U6.8, U7.1, U8.5, U9.15, U10.51, U10.52, U10.53
3.3V2: C49.1, C53.1, C54.1, C55.1, C61.1, C62.1, C63.1, C66.1, C67.1, C72.1, D27.A, I2C2.2, LTE_NI_LED2.2, LTE_ON_LED2.2, R53.2, R58.2, R62.2, R69.1, U13.8, U14.1, U15.5, U16.15, U17.51, U17.52, U17.53
3.3V3: C73.1, C77.1, C78.1, C79.1, C85.1, C86.1, C87.1, C90.1, C91.1, C96.1, D37.A, I2C3.2, LTE_NI_LED3.2, LTE_ON_LED3.2, R77.2, R82.2, R86.2, R93.1, U19.8, U20.1, U21.5, U22.15, U23.51, U23.52, U23.53
3.3V4: C97.1, C101.1, C102.1, C103.1, C109.1, C110.1, C111.1, C114.1, C115.1, C120.1, D47.A, I2C4.2, LTE_NI_LED4.2, LTE_ON_LED4.2, R101.2, R106.2, R110.2, R117.1, U25.8, U26.1, U27.5, U28.15, U29.51, U29.52, U29.53
3.3V5: C121.1, C125.1, C126.1, C127.1, C133.1, C134.1, C135.1, C138.1, C139.1, C144.1, D57.A, I2C5.2, LTE_NI_LED5.2, LTE_ON_LED5.2, R125.2, R130.2, R134.2, R141.1, U31.8, U32.1, U33.5, U34.15, U35.51, U35.52, U35.53
3.3V_IN: J1.73, R2.2, R33.2
3.3V_IN1: J5.73, R16.2, R37.2
3.3V_IN2: J11.73, R54.2, R71.2
3.3V_IN3: J16.73, R78.2, R95.2
3.3V_IN4: J21.73, R102.2, R119.2
3.3V_IN5: J26.73, R126.2, R143.2
ANT_REG_EN: ANT_REG_EN.1, R2.1, U3.3
ANT_REG_EN1: ANT_REG_EN1.1, R37.1, U12.3
ANT_REG_EN2: ANT_REG_EN2.1, R71.1, U18.3
ANT_REG_EN3: ANT_REG_EN3.1, R95.1, U24.3
ANT_REG_EN4: ANT_REG_EN4.1, R119.1, U30.3
ANT_REG_EN5: ANT_REG_EN5.1, R143.1, U36.3
CTS: J1.18, U2.11
CTS1: J5.18, U9.11
CTS2: J11.18, U16.11
CTS3: J16.18, U22.11
CTS4: J21.18, U28.11
CTS5: J26.18, U34.11
EN: J1.71, R33.1, U5.5
EN1: J5.71, R16.1, U7.5
EN2: J11.71, R54.1, U14.5
EN3: J16.71, R78.1, U20.5
EN4: J21.71, R102.1, U26.5
EN5: J26.71, R126.1, U32.5
EWP: J1.40, R11.1, U4.7, WP.2
EWP1: J5.40, R15.1, U6.7, WP1.2
EWP2: J11.40, R53.1, U13.7, WP2.2
EWP3: J16.40, R77.1, U19.7, WP3.2
EWP4: J21.40, R101.1, U25.7, WP4.2
EWP5: J26.40, R125.1, U31.7, WP5.2
GND: 3V3_LED.1, C1.2, C2.2, C3.2, C4.2, C5.2, C9.2, C17.2, C18.2, C19.2, C20.2, C21.-, C22.2, C23.2, C24.2, C25.2, C28.2, C30.2, C32.2, C36.1, C37.2, C38.1, C39.2, C40.1, D4.2, D6.2, D10.2, D15.2, D15.5, J1.1, J1.2, J1.8, J1.33, J1.39, J1.45, J1.75, J1.GND1, J1.GND2, J1.GND3, J1.GND4, J1.GND5, J1.GND6, J2.1, J2.2, J3.GND, J3.GND2, J4.1, J4.2, J9.A1, J9.A2, J9.A3, J9.A4, J9.C5, Q2.2, Q3.2, Q5.2, Q6.2, R1.2, R8.1, R9.1, R32.1, R39.2, S3.3, S3.4, U1.1, U1.3, U1.5, U1.14, U1.20, U1.21, U1.22, U1.30, U1.32, U1.43, U1.50, U1.54, U1.55, U1.57, U1.58, U1.59, U1.60, U1.61, U1.63, U1.64, U1.65, U1.66, U1.67, U1.68, U1.69, U1.70, U1.71, U1.72, U1.73, U1.74, U1.75, U1.76, U1.77, U1.78, U1.79, U1.80, U1.81, U1.82, U1.83, U1.84, U1.85, U1.86, U1.87, U1.88, U1.89, U1.90, U1.91, U1.92, U1.93, U1.94, U1.95, U1.96, U2.1, U2.7, U2.9, U2.10, U3.2, U4.4, U5.4, U5.EP, U11.3, USB_SHLD.2, WP.1
GND1: 3V3_LED1.1, C6.2, C7.2, C8.2, C10.-, C11.2, C12.2, C13.2, C14.2, C15.2, C16.1, C26.1, C27.1, C29.2, C31.2, C34.2, C41.2, C42.2, C43.2, C44.2, C45.2, C46.2, C47.2, C48.2, D8.2, D8.5, D14.2, D19.2, D20.2, J5.1, J5.2, J5.8, J5.33, J5.39, J5.45, J5.75, J5.GND1, J5.GND2, J5.GND3, J5.GND4, J5.GND5, J5.GND6, J6.GND, J6.GND2, J7.1, J7.2, J8.A1, J8.A2, J8.A3, J8.A4, J8.C5, J10.1, J10.2, Q1.2, Q4.2, Q7.2, Q8.2, R7.1, R12.1, R21.2, R22.1, R30.2, S1.3, S1.4, U6.4, U7.4, U7.EP, U8.3, U9.1, U9.7, U9.9, U9.10, U10.1, U10.3, U10.5, U10.14, U10.20, U10.21, U10.22, U10.30, U10.32, U10.43, U10.50, U10.54, U10.55, U10.57, U10.58, U10.59, U10.60, U10.61, U10.63, U10.64, U10.65, U10.66, U10.67, U10.68, U10.69, U10.70, U10.71, U10.72, U10.73, U10.74, U10.75, U10.76, U10.77, U10.78, U10.79, U10.80, U10.81, U10.82, U10.83, U10.84, U10.85, U10.86, U10.87, U10.88, U10.89, U10.90, U10.91, U10.92, U10.93, U10.94, U10.95, U10.96, U12.2, USB_SHLD1.2, WP1.1
GND2: 3V3_LED2.1, C49.2, C50.2, C51.2, C52.-, C53.2, C54.2, C55.2, C56.2, C57.2, C58.1, C59.1, C60.1, C61.2, C62.2, C63.2, C65.2, C66.2, C67.2, C68.2, C69.2, C70.2, C71.2, C72.2, D23.2, D23.5, D28.2, D29.2, D30.2, J11.1, J11.2, J11.8, J11.33, J11.39, J11.45, J11.75, J11.GND1, J11.GND2, J11.GND3, J11.GND4, J11.GND5, J11.GND6, J12.GND, J12.GND2, J13.1, J13.2, J14.A1, J14.A2, J14.A3, J14.A4, J14.C5, J15.1, J15.2, Q9.2, Q10.2, Q11.2, Q12.2, R42.1, R44.1, R59.2, R60.1, R66.2, S2.3, S2.4, U13.4, U14.4, U14.EP, U15.3, U16.1, U16.7, U16.9, U16.10, U17.1, U17.3, U17.5, U17.14, U17.20, U17.21, U17.22, U17.30, U17.32, U17.43, U17.50, U17.54, U17.55, U17.57, U17.58, U17.59, U17.60, U17.61, U17.63, U17.64, U17.65, U17.66, U17.67, U17.68, U17.69, U17.70, U17.71, U17.72, U17.73, U17.74, U17.75, U17.76, U17.77, U17.78, U17.79, U17.80, U17.81, U17.82, U17.83, U17.84, U17.85, U17.86, U17.87, U17.88, U17.89, U17.90, U17.91, U17.92, U17.93, U17.94, U17.95, U17.96, U18.2, USB_SHLD2.2, WP2.1
GND3: 3V3_LED3.1, C73.2, C74.2, C75.2, C76.-, C77.2, C78.2, C79.2, C80.2, C81.2, C82.1, C83.1, C84.1, C85.2, C86.2, C87.2, C89.2, C90.2, C91.2, C92.2, C93.2, C94.2, C95.2, C96.2, D33.2, D33.5, D38.2, D39.2, D40.2, J16.1, J16.2, J16.8, J16.33, J16.39, J16.45, J16.75, J16.GND1, J16.GND2, J16.GND3, J16.GND4, J16.GND5, J16.GND6, J17.GND, J17.GND2, J18.1, J18.2, J19.A1, J19.A2, J19.A3, J19.A4, J19.C5, J20.1, J20.2, Q13.2, Q14.2, Q15.2, Q16.2, R73.1, R74.1, R83.2, R84.1, R90.2, S4.3, S4.4, U19.4, U20.4, U20.EP, U21.3, U22.1, U22.7, U22.9, U22.10, U23.1, U23.3, U23.5, U23.14, U23.20, U23.21, U23.22, U23.30, U23.32, U23.43, U23.50, U23.54, U23.55, U23.57, U23.58, U23.59, U23.60, U23.61, U23.63, U23.64, U23.65, U23.66, U23.67, U23.68, U23.69, U23.70, U23.71, U23.72, U23.73, U23.74, U23.75, U23.76, U23.77, U23.78, U23.79, U23.80, U23.81, U23.82, U23.83, U23.84, U23.85, U23.86, U23.87, U23.88, U23.89, U23.90, U23.91, U23.92, U23.93, U23.94, U23.95, U23.96, U24.2, USB_SHLD3.2, WP3.1
GND4: 3V3_LED4.1, C97.2, C98.2, C99.2, C100.-, C101.2, C102.2, C103.2, C104.2, C105.2, C106.1, C107.1, C108.1, C109.2, C110.2, C111.2, C113.2, C114.2, C115.2, C116.2, C117.2, C118.2, C119.2, C120.2, D43.2, D43.5, D48.2, D49.2, D50.2, J21.1, J21.2, J21.8, J21.33, J21.39, J21.45, J21.75, J21.GND1, J21.GND2, J21.GND3, J21.GND4, J21.GND5, J21.GND6, J22.GND, J22.GND2, J23.1, J23.2, J24.A1, J24.A2, J24.A3, J24.A4, J24.C5, J25.1, J25.2, Q17.2, Q18.2, Q19.2, Q20.2, R97.1, R98.1, R107.2, R108.1, R114.2, S5.3, S5.4, U25.4, U26.4, U26.EP, U27.3, U28.1, U28.7, U28.9, U28.10, U29.1, U29.3, U29.5, U29.14, U29.20, U29.21, U29.22, U29.30, U29.32, U29.43, U29.50, U29.54, U29.55, U29.57, U29.58, U29.59, U29.60, U29.61, U29.63, U29.64, U29.65, U29.66, U29.67, U29.68, U29.69, U29.70, U29.71, U29.72, U29.73, U29.74, U29.75, U29.76, U29.77, U29.78, U29.79, U29.80, U29.81, U29.82, U29.83, U29.84, U29.85, U29.86, U29.87, U29.88, U29.89, U29.90, U29.91, U29.92, U29.93, U29.94, U29.95, U29.96, U30.2, USB_SHLD4.2, WP4.1
GND5: 3V3_LED5.1, C121.2, C122.2, C123.2, C124.-, C125.2, C126.2, C127.2, C128.2, C129.2, C130.1, C131.1, C132.1, C133.2, C134.2, C135.2, C137.2, C138.2, C139.2, C140.2, C141.2, C142.2, C143.2, C144.2, D53.2, D53.5, D58.2, D59.2, D60.2, J26.1, J26.2, J26.8, J26.33, J26.39, J26.45, J26.75, J26.GND1, J26.GND2, J26.GND3, J26.GND4, J26.GND5, J26.GND6, J27.GND, J27.GND2, J28.1, J28.2, J29.A1, J29.A2, J29.A3, J29.A4, J29.C5, J30.1, J30.2, Q21.2, Q22.2, Q23.2, Q24.2, R121.1, R122.1, R131.2, R132.1, R138.2, S6.3, S6.4, U31.4, U32.4, U32.EP, U33.3, U34.1, U34.7, U34.9, U34.10, U35.1, U35.3, U35.5, U35.14, U35.20, U35.21, U35.22, U35.30, U35.32, U35.43, U35.50, U35.54, U35.55, U35.57, U35.58, U35.59, U35.60, U35.61, U35.63, U35.64, U35.65, U35.66, U35.67, U35.68, U35.69, U35.70, U35.71, U35.72, U35.73, U35.74, U35.75, U35.76, U35.77, U35.78, U35.79, U35.80, U35.81, U35.82, U35.83, U35.84, U35.85, U35.86, U35.87, U35.88, U35.89, U35.90, U35.91, U35.92, U35.93, U35.94, U35.95, U35.96, U36.2, USB_SHLD5.2, WP5.1
GNSS_ANT: D4.1, FB1.2, J4.FEED, U1.31
GNSS_ANT1: D14.1, FB2.2, J10.FEED, U10.31
GNSS_ANT2: D28.1, FB3.2, J15.FEED, U17.31
GNSS_ANT3: D38.1, FB4.2, J20.FEED, U23.31
GNSS_ANT4: D48.1, FB5.2, J25.FEED, U29.31
GNSS_ANT5: D58.1, FB6.2, J30.FEED, U35.31
I2C_SCL: J1.21, R6.1, U4.6
I2C_SCL1: J5.21, R13.1, U6.6
I2C_SCL2: J11.21, R51.1, U13.6
I2C_SCL3: J16.21, R75.1, U19.6
I2C_SCL4: J21.21, R99.1, U25.6
I2C_SCL5: J26.21, R123.1, U31.6
I2C_SDA: J1.19, R10.1, U4.5
I2C_SDA1: J5.19, R14.1, U6.5
I2C_SDA2: J11.19, R52.1, U13.5
I2C_SDA3: J16.19, R76.1, U19.5
I2C_SDA4: J21.19, R100.1, U25.5
I2C_SDA5: J26.19, R124.1, U31.5
LTE_18_!RESET!: Q3.3, U1.18
LTE_18_!RESET!1: Q4.3, U10.18
LTE_18_!RESET!2: Q10.3, U17.18
LTE_18_!RESET!3: Q14.3, U23.18
LTE_18_!RESET!4: Q18.3, U29.18
LTE_18_!RESET!5: Q22.3, U35.18
LTE_18_CTS: U1.11, U2.6
LTE_18_CTS1: U9.6, U10.11
LTE_18_CTS2: U16.6, U17.11
LTE_18_CTS3: U22.6, U23.11
LTE_18_CTS4: U28.6, U29.11
LTE_18_CTS5: U34.6, U35.11
LTE_18_DTR: R1.1, U1.9
LTE_18_DTR1: R30.1, U10.9
LTE_18_DTR2: R66.1, U17.9
LTE_18_DTR3: R90.1, U23.9
LTE_18_DTR4: R114.1, U29.9
LTE_18_DTR5: R138.1, U35.9
LTE_18_NI: R48.1, U1.16
LTE_18_NI1: R19.1, U10.16
LTE_18_NI2: R57.1, U17.16
LTE_18_NI3: R81.1, U23.16
LTE_18_NI4: R105.1, U29.16
LTE_18_NI5: R129.1, U35.16
LTE_18_PWR_ON: Q2.3, S3.1, S3.2, U1.15
LTE_18_PWR_ON1: Q1.3, S1.1, S1.2, U10.15
LTE_18_PWR_ON2: Q9.3, S2.1, S2.2, U17.15
LTE_18_PWR_ON3: Q13.3, S4.1, S4.2, U23.15
LTE_18_PWR_ON4: Q17.3, S5.1, S5.2, U29.15
LTE_18_PWR_ON5: Q21.3, S6.1, S6.2, U35.15
LTE_18_RI: LTE_RI_LED.2, U1.7
LTE_18_RI1: LTE_RI_LED1.2, U10.7
LTE_18_RI2: LTE_RI_LED2.2, U17.7
LTE_18_RI3: LTE_RI_LED3.2, U23.7
LTE_18_RI4: LTE_RI_LED4.2, U29.7
LTE_18_RI5: LTE_RI_LED5.2, U35.7
LTE_18_RTS: U1.10, U2.5
LTE_18_RTS1: U9.5, U10.10
LTE_18_RTS2: U16.5, U17.10
LTE_18_RTS3: U22.5, U23.10
LTE_18_RTS4: U28.5, U29.10
LTE_18_RTS5: U34.5, U35.10
LTE_18_RXO: U1.13, U2.4
LTE_18_RXO1: U9.4, U10.13
LTE_18_RXO2: U16.4, U17.13
LTE_18_RXO3: U22.4, U23.13
LTE_18_RXO4: U28.4, U29.13
LTE_18_RXO5: U34.4, U35.13
LTE_18_TXI: U1.12, U2.3
LTE_18_TXI1: U9.3, U10.12
LTE_18_TXI2: U16.3, U17.12
LTE_18_TXI3: U22.3, U23.12
LTE_18_TXI4: U28.3, U29.12
LTE_18_TXI5: U34.3, U35.12
LTE_!NI!: LTE_NI.1, Q6.3, R49.1, R50.1
LTE_!NI!1: LTE_NI1.1, Q7.3, R20.1, R27.1
LTE_!NI!2: LTE_NI2.1, Q11.3, R58.1, R63.1
LTE_!NI!3: LTE_NI3.1, Q15.3, R82.1, R87.1
LTE_!NI!4: LTE_NI4.1, Q19.3, R106.1, R111.1
LTE_!NI!5: LTE_NI5.1, Q23.3, R130.1, R135.1
LTE_!ON!: LTE_ON.1, Q5.3, R46.1, R47.1
LTE_!ON!1: LTE_ON1.1, Q8.3, R26.1, R29.1
LTE_!ON!2: LTE_ON2.1, Q12.3, R62.1, R65.1
LTE_!ON!3: LTE_ON3.1, Q16.3, R86.1, R89.1
LTE_!ON!4: LTE_ON4.1, Q20.3, R110.1, R113.1
LTE_!ON!5: LTE_ON5.1, Q24.3, R134.1, R137.1
LTE_!RESET!: LTE_RESET.1, R5.2, U11.2
LTE_!RESET!1: LTE_RESET1.1, R35.2, U8.2
LTE_!RESET!2: LTE_RESET2.1, R69.2, U15.2
LTE_!RESET!3: LTE_RESET3.1, R93.2, U21.2
LTE_!RESET!4: LTE_RESET4.1, R117.2, U27.2
LTE_!RESET!5: LTE_RESET5.1, R141.2, U33.2
LTE_ANT: C33.1, U1.56
LTE_ANT1: C35.1, U10.56
LTE_ANT2: C64.1, U17.56
LTE_ANT3: C88.1, U23.56
LTE_ANT4: C112.1, U29.56
LTE_ANT5: C136.1, U35.56
LTE_PWR_ON: LTE_PWR_ON.1, R39.1, R40.1
LTE_PWR_ON1: LTE_PWR_ON1.1, R17.1, R21.1
LTE_PWR_ON2: LTE_PWR_ON2.1, R55.1, R59.1
LTE_PWR_ON3: LTE_PWR_ON3.1, R79.1, R83.1
LTE_PWR_ON4: LTE_PWR_ON4.1, R103.1, R107.1
LTE_PWR_ON5: LTE_PWR_ON5.1, R127.1, R131.1
unnamed: J1.36, U4.1
unnamed: J3.A5, R8.2
unnamed: J1.57, LTE_PWR_ON.2
unnamed: ANT_REG_EN.2, J1.61
unnamed: J3.B5, R9.2
unnamed: 3V3_LED.2, R4.1
unnamed: D3.C, R4.2
unnamed: J1.32, U4.3
unnamed: J1.34, U4.2
unnamed: D6.1, J3.A6, J3.B6
unnamed: C33.2, D10.1, J2.FEED, L2.P$2
unnamed: J1.47, LTE_NI.2
unnamed: I2C.1, R10.2
unnamed: I2C.3, R6.2
unnamed: D6.3, J3.A7, J3.B7
unnamed: J1.49, LTE_ON.2
unnamed: J1.51, LTE_RESET.2
unnamed: C4.1, L2.P$1, R23.2
unnamed: D18.A, LTE_NI_LED.1
unnamed: LTE_RI_LED.1, R43.1
unnamed: D17.A, LTE_ON_LED.1
unnamed: F2.1, J3.VBUS1, J3.VBUS2
unnamed: 3V3_LED1.2, R31.1
unnamed: C1.1, C2.1, R24.1, U3.5
unnamed: C3.1, FB1.1, R24.2, TP22.1
unnamed: Q2.1, R40.2
unnamed: Q3.1, R41.2
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

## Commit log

2023-04-11 Copying in v02 proto design
    [SparkFun_MicroMod_Function_SARA-R5.brd, SparkFun_MicroMod_Function_SARA-R5.sch]
2023-04-11 added GNSS antenna U.FL
    -added GNSS antenna U.FL, with supporting circuitry and power control
    -rotated module 90 degrees
    [SparkFun_MicroMod_Function_SARA-R5.brd, SparkFun_MicroMod_Function_SARA-R5.sch]
2023-04-12 Silk adjustments
    [SparkFun_MicroMod_Function_SARA-R5.brd, SparkFun_MicroMod_Function_SARA-R5.sch]
2023-04-12 Increase VUSB trace to 30mil
    -u.fl FP library update - adds restrict underneath
    [SparkFun_MicroMod_Function_SARA-R5.brd, SparkFun_MicroMod_Function_SARA-R5.sch]
2023-04-12 top poly to 7mil and sch cleanup
    [SparkFun_MicroMod_Function_SARA-R5.brd, SparkFun_MicroMod_Function_SARA-R5.sch]
2023-04-12 USB D+ and D- routing
    -re-did calcs and changed to 9 mil width with 8 mil spacing.
    [SparkFun_MicroMod_Function_SARA-R5.brd, SparkFun_MicroMod_Function_SARA-R5.sch]
2023-04-12 update LEDs and limiting resistor values to new standards
    [SparkFun_MicroMod_Function_SARA-R5.brd, SparkFun_MicroMod_Function_SARA-R5.sch]
2023-04-12 added oshw logo
    -also added label to ANT_REG_EN jumper
    [SparkFun_MicroMod_Function_SARA-R5.brd, SparkFun_MicroMod_Function_SARA-R5.sch]
2023-04-12 library work
    -switching some parts over to SFE libraries
    [SparkFun_MicroMod_Function_SARA-R5.brd, SparkFun_MicroMod_Function_SARA-R5.sch]
2023-04-14 TVS diodes moved closer to connectors
    -more gnd vias along rf traces and everywhere.
    [SparkFun_MicroMod_Function_SARA-R5.brd]
2023-04-14 approving some drc errors
    [SparkFun_MicroMod_Function_SARA-R5.brd]
2023-04-17 pre-review changes (part 1)
    -renamed all jumpers to match silk
    -replaced I2C pullups to 2.2K
    -Schematic Cleanup
    -silk lines between tight passives in a row
    -fixed acid trap off of pad 12
    -tweaked via position near GND pad 14 to allow for flow
    -routed GND to connect inner and perimeter GND pads on module.
    -nudging of vias and traces to improve some gnd pour flow
    -added mini VCC polygon over m.2 connector pads for better flow
    [SparkFun_MicroMod_Function_SARA-R5.brd, SparkFun_MicroMod_Function_SARA-R5.sch]
2023-04-17 Moved VCCIO away from LTE_ANT
    [SparkFun_MicroMod_Function_SARA-R5.brd]
2023-04-18 USB_SHLD jumper added
    [SparkFun_MicroMod_Function_SARA-R5.brd, SparkFun_MicroMod_Function_SARA-R5.sch]
2023-04-18 Sim connector re-routing
    -IC2 ref to U2
    -Updated Nano SIM FP to have tRestrict area underneath
    -moved traces under the SIM connector to bottom layer
    [SparkFun_MicroMod_Function_SARA-R5.brd, SparkFun_MicroMod_Function_SARA-R5.sch]
2023-04-19 More changes from group review
    -Now it's a 4-layer, removed some 3.3V traces from bottom copper, added vias as necessary to connect to 3.3V inner layer.
    -Changed where regulators (U3 and U5) enable pins are tied up to. They are now tied up to the 3.3V provided by the MM Main board. Previously, they were connected to VIN, which could be higher than 3.3V and damage enable control GPIO on some processor boards.
    -Disconnected V_USB from MM m.2 connector.
    [SparkFun_MicroMod_Function_SARA-R5.brd, SparkFun_MicroMod_Function_SARA-R5.sch]
2023-04-19 ESD diode position and removed L1
    -Moved ESD diode D10 to the other side of L2, to put it directly next to the u.fl connector
    -removed L1 (it was previously DNP)
    [SparkFun_MicroMod_Function_SARA-R5.brd, SparkFun_MicroMod_Function_SARA-R5.sch]
2023-04-19 acid traps and measures
    -fixed some acid traps and routed some GNDs off of pads
    -measures to everything
    [SparkFun_MicroMod_Function_SARA-R5.brd, SparkFun_MicroMod_Function_SARA-R5.sch]
2023-04-20 USB lines updated for correct impedance calcs
    -updated trace width and spacing to hit a 90 ohm differential impedance on D+/D-
    -updated calculation text paragraph in SCH
    [SparkFun_MicroMod_Function_SARA-R5.brd, SparkFun_MicroMod_Function_SARA-R5.sch]
2023-04-20 ESD diode on D+ and D- USB lines
    [SparkFun_MicroMod_Function_SARA-R5.brd, SparkFun_MicroMod_Function_SARA-R5.sch]
2023-04-20 RF traces corrected to 12.3mil
    -also updated calc paragraph in SCH
    [SparkFun_MicroMod_Function_SARA-R5.brd, SparkFun_MicroMod_Function_SARA-R5.sch]
2023-04-21 LED disable jumpers added
    -LTE_RI_LED, LTE_NI_LED, LTE_ON
    [SparkFun_MicroMod_Function_SARA-R5.brd, SparkFun_MicroMod_Function_SARA-R5.sch]
2023-04-21 add 0.1uF cap on VCCB for level shifter
    [SparkFun_MicroMod_Function_SARA-R5.brd, SparkFun_MicroMod_Function_SARA-R5.sch]
2023-04-21 Library work and BOM consolidation
    [SparkFun_MicroMod_Function_SARA-R5.brd, SparkFun_MicroMod_Function_SARA-R5.sch]
2023-04-21 added PTC fuse to USB input
    [SparkFun_MicroMod_Function_SARA-R5.brd, SparkFun_MicroMod_Function_SARA-R5.sch]
2023-04-24 SIM clock routing to a "Y" to avoid 90 degree.
    [SparkFun_MicroMod_Function_SARA-R5.brd]
2023-04-24 Moved LTE "ON" button north away from the M.2 conn
    -note, moved the silk label to the south side of the button to allow this shift.
    [SparkFun_MicroMod_Function_SARA-R5.brd]
2023-04-24 SIM clock line re-routed to a "teardrop" instead of 90
    [SparkFun_MicroMod_Function_SARA-R5.brd]
2023-04-24 nudging small things
    -nudged via on LTE_18_NI to get better gnd flow
    -EN net nudged to make better gnd flow
    -adjusted measures to avoid overlap with milling text
    [SparkFun_MicroMod_Function_SARA-R5.brd]
2023-04-27 LTE_RESET changed to 10K
    -LTE_RESET was not working with 100K, so changed to 10K
    -Moved ANT regulator power control to different F pin, to avoid RX/TX sharing conflict
    -corrected SCH text note about shared pins for RX1/TX1 on esp32
    -corrected RTS1/CTS1 back so they are not swapped on this FB.
    [SparkFun_MicroMod_Function_SARA-R5.brd, SparkFun_MicroMod_Function_SARA-R5.sch]
2023-05-01 Eng run checklist
    -Minor schematic cleanup and tightening
    -added some jumper text objects to sch
    -added layer 1/2/3/4 text to copper layers
    -switched to larger TP
    -bumper version to v10
    [SparkFun_MicroMod_Function_SARA-R5.brd, SparkFun_MicroMod_Function_SARA-R5.sch]
2023-05-01 production panel v10
    -Note, I also added some more specific ordering instructions to the single brd file, that were flagged by the panelizer tool. No changed to the design though.
    [SparkFun_MicroMod_Function_SARA-R5-Panel.GBL, SparkFun_MicroMod_Function_SARA-R5-Panel.GBO, SparkFun_MicroMod_Function_SARA-R5-Panel.GBP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]
2023-05-01 minor sch aesthetic updates
    -changed one V_USB flag to a power symbol
    -updated version in s SCH to v10
    [SparkFun_MicroMod_Function_SARA-R5.sch]
2023-05-01 added version number into the gerber zip file name
2023-05-22 Corrected RTS pulldown - bumped to v11
    -Pull down was incorrectly on CTS. It is now correctly on RTS.
    -DIR of channels 3/4 on U2 have also been corrected to reflect RTS/CTS as needed.
    -bumped version to v11
    [SparkFun_MicroMod_Function_SARA-R5.brd, SparkFun_MicroMod_Function_SARA-R5.sch]
2023-05-31 R33 set to DNP (EN pullup on vreg)
    -R33 is DNP. This was conflicting with GPIO12 (strapping pin) on the ESP32 PB
    -R46 changed to 100 for brighter green LED.
    [SparkFun_MicroMod_Function_SARA-R5.brd, SparkFun_MicroMod_Function_SARA-R5.sch]
2023-05-31 v11 production panel and gerbers
    [SparkFun_MicroMod_Function_SARA-R5-Panel.brd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]
2023-07-12 On LED changed to Red (DIO-17976)
    [SparkFun_MicroMod_Function_SARA-R5-Panel.brd, SparkFun_MicroMod_Function_SARA-R5.brd, SparkFun_MicroMod_Function_SARA-R5.sch]
2023-11-14 Remove "Hide" from Style
    - Remove the "hide" from the style to ensure that the images/tutorials show up when printing

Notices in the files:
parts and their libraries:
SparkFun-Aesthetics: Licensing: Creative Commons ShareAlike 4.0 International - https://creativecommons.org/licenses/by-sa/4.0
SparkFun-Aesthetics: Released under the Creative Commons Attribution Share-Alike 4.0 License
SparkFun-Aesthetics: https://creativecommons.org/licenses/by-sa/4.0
